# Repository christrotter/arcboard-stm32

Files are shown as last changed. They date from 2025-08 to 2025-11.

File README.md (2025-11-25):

# 2025/11/25 update
Ok, we found the main problem.
The Schottky diode on the main VBUS inbound power leg (just after the main polyfuse) was the problem.  After many hours of troubleshooting, we discovered that it was the thing getting hot.
More digging revealed that it had a 1A max, and after 75C its performance tanked pretty fast.  In practice it could tolerate about 0.5A before overheating got out of hand.
I replaced it with a bodge wire and the overheating problem went away - the board is now just warm with 1.1A going through it - probably some other components are 1A-rated.  I did not anticipate drawing this much current... my bad!
As a side effect of removing the diode, VBUS detection no longer works properly, so that needs to be disabled in code.

The next iteration will be a massive overhaul, so I'm not going to fix the problem.  In theory, we need both a higher quality component, a bigger package, and higher current rating.

# 2025/11/23 update 
I've, unsurprisingly, found some flaws.
Aside from the flaws mentioned (that were fixed), there's something very wrong with the power filter circuit or power trace widths.
Everything works, but it consumes 2x the power it should be consuming, and overwhelms the power traces so that they get rather hot.  I had to reduce brightness quite a bit to keep it at 'warm' levels.  Unfortunately I don't own an infrared camera, so only have temperature sensing by feel, but the area that gets hottest is in the power filter area.  I tried using the solder pad bypass, but no difference.
So, feels like it's a trace problem...?  Or maybe a bad component?  Will update when I figure it out.
If you're only running the Cyboard pcbs, PMW, dpad/paddles, it consumes about 0.25A per side.

# stm32-inator
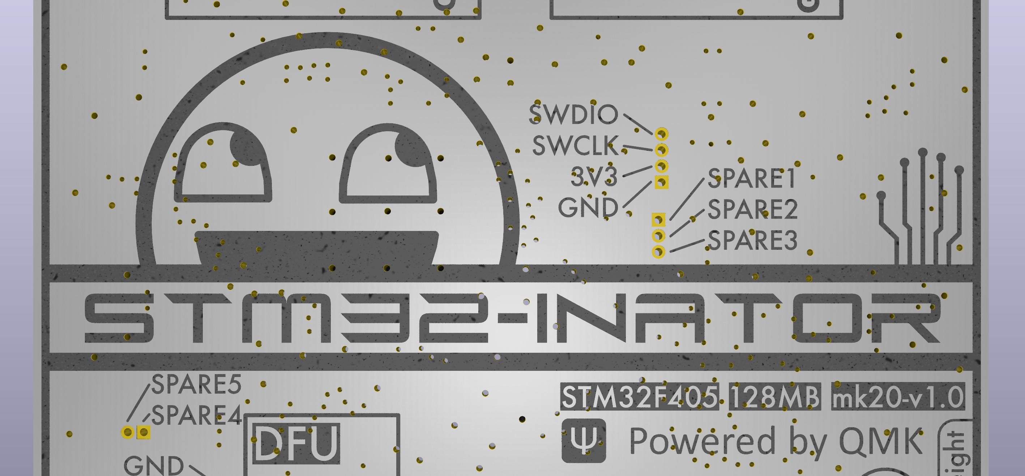
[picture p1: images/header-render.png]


In the search for better performance, I moved from [RP2040](https://github.com/christrotter/mk19-rp2040) (`125mhz`) to STM32F405 (`168mhz`).  Getting familiar with STM32 also allows me more confidence to move to the H7** chips in future (`550mhz`).

`v1.0 board has been tested - works w. 2 easy bodges & code.  Issues fixed in v1.1 - won't be ordering that, so untested - minor changes, should be fine?`

Many thanks to Drashna, burkfers, GeorgeN, badjeff, and the various people (tzarc) I snaggled stuff from - as always, these projects are a community effort.

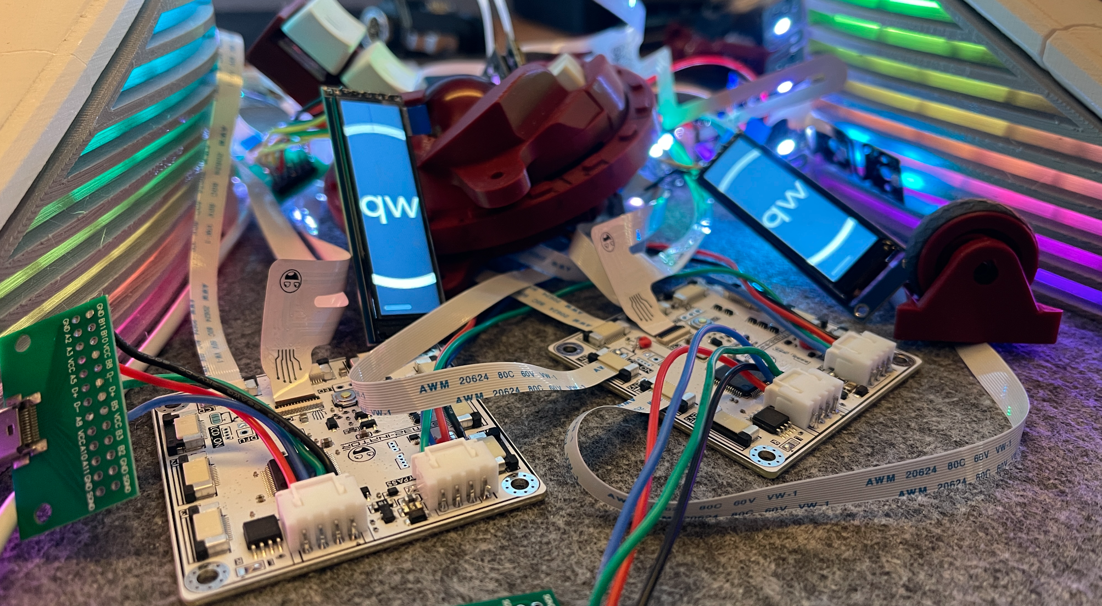
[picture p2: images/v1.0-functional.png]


## First run production
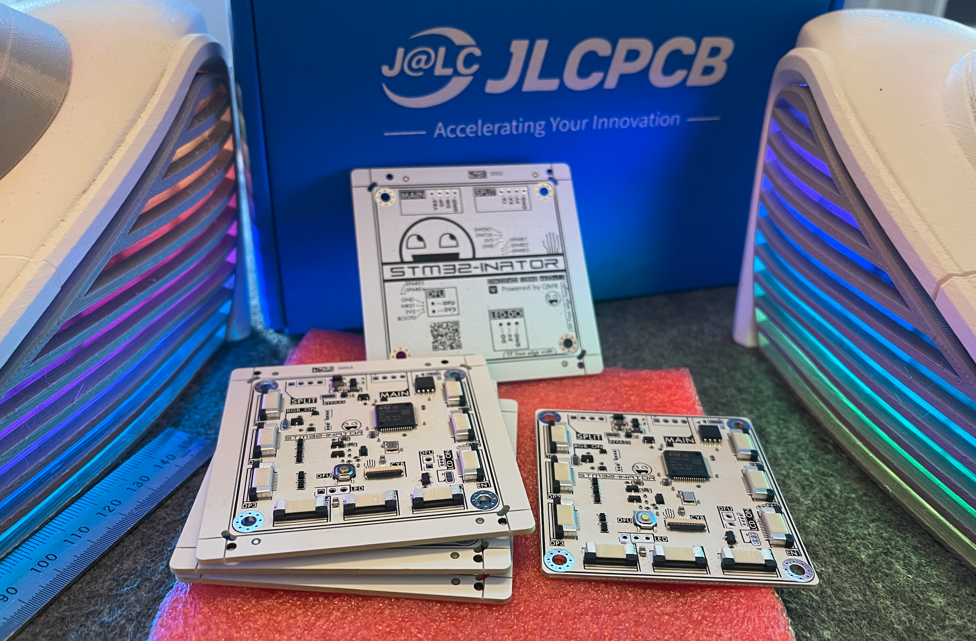
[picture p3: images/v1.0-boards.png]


### issues
While things work, there are some problems...
- both mosfets are incorrectly wired up (maybe bad footprint?), and frankly i don't see a need for them as we're not doing batteries; the original thought was 'full power down', dunno if that's a real need; clipping them off removes the issue, and there are sufficient workarounds
- the DFU circuit cannot tolerate the LCD being plugged in; something? in that circuit prevents the cap from charging up
  - there is something foundational here that I am not equipped to deal with atm; 'works, until 3v3 devices in play'

### discoveries
...and some 'you have to try it to know' discoveries, and secondary pcb issues...
- 8mhz crystal is not the default in QMK -> 12mhz is; can be fixed in a few lines of code, but not ideal
- turns out 10 ffc cables are pretty annoying and i'd have been better served moving to two custom ffc cables
- the ffc connectors are kinda sad to use; need to make some kind of tool? -> kinda points in the direction of hot plate if i want to be choosy about parts
- the horizontal JST-XH fit...barely... i neglected to account for 'space to slide the connector in' and so you need to trim the JST housings to avoid fouling on parts - move away from this design in future, JST-PH?

### wins
...but not all is lost:
- remote usb port works absolutely fine
- DFU circuit is super rad (when it works)
- no awful bodging required this time!
- the diode arrays work
- STM32 cpu/etc all works
- silkscreen looks good
- matrix works
- spi pmw/lcd work

### conclusion
All in all, this is a win, and it'll work for mk20.

# Features
- STM32F405RGTx w. 12mhz crystal
- 128mb external flash via SPI
  - Because I Can™ by drashna®
- FFC connections (mostly), using VIK-footprinted 12-pin 0.5mm pitch connectors
- Rough footprint is 60x60mm
- Designed for remote-mount USB and split-serial ports
- WS2812 signal conversion to 5v
- Two-stage DFU button, on-board for convenience, headers for an external button
  - Press for reset
  - Hold for ~4s to enter DFU mode for flashing
  - `NOTE: when 3v3 devices are connected, the hold-for-dfu stops working :'(`
- Designed for Arcboard-mk20 peripherals
  - 4x dpad outputs (5rows, 1col, LED DI/DO, 5v/gnd)
  - 3x encoders outputs (encoder A/B, 3.3v/gnd)
  - 1x SPI PMW output (usual pins)
  - 1x SPI LCD output (usual pins)
  - 1x 25-pin Cyboard connector (0.3mm FPC connector for [Cyboard](https://www.cyboard.digital/product-page/dactyl-flex-pcbs) connectivity (or via [this](https://github.com/christrotter/mk19-flex-pcb)))
- 2-layer design for simplicity and cost

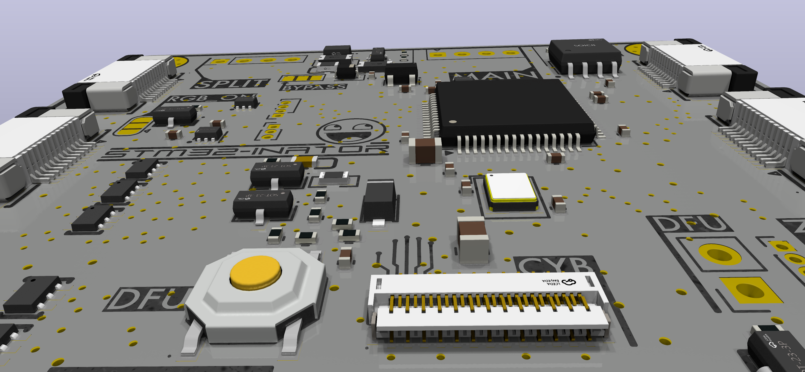
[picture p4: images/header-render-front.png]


# Design notes & decisions
## CPU
I had originally wanted to go whole-hog and start with STM32H723 (as mentioned, 550mhz), but there are a lot of Chibios/QMK config bits to set that are not well-documented at present.  As 550mhz is super overkill for a keyboard, it's not a widely used chip - so examples are sparse or non-existent.

Drashna recommended starting with F405 and so who am I to second-guess them.

## Flash
At present (August 2025) QMK cannot support external flash for code execution, but feature work is on-going.  I was advised by Drashna to include the flash chip for future-proofing.  My hope is to use it for icon storage and the like.

Why 128mb?  Because it was a few bucks difference compared to 16mb, and there was no real (evident) reason not to.

## Remote-mount USB/split-serial port
This is mostly a mk20 design thing - I wanted to have the split-serial connector be at an angle, not coming off the back of the board.  When the ports are in the back, it's awkward to figure out which one is main, which one is split.  Drashna pointed out that he's been using [these](https://www.aliexpress.com/item/1005005997783735.html) which have 12cm cables and has no USB issues at all.  After a hiccup with JLC PCBA design review, I had to cancel the order and re-submit, and took the plunge...there was no room for both an on-board port and breakout pins.

  - JLC PCBA charges ~C$6 per usb port (per board...), and I've had soldering issues w. those components before
  - No more fuss with v-cut layer drama and them wanting me to use EasyEDA
  - I don't have a USB-C source, and I'm not selling this, so...whatever...
  - note that the remote-port needs to have 5.1k pull-down resistors on the CC lines to function on a USB-C host port

## Device/peripheral connectivity
I explicitly wanted to move away from JST-XH (or any soldered connector) because of pain issues doing all that soldering.  This board's goal was 'minimize soldering, maximize PCBA-ing'.

Given that I like the [VIK standard](https://github.com/sadekbaroudi/vik), I went with VIK footprints - 12-pin 0.5mm pitch FFC.  Not all of the pinouts are VIK-correct, but at least it keeps things somewhat standardized.

## Breakouts
To save space while also future-proofing, I was advised to include breakouts (thx GeorgeN/burkfers).

- Main USB & Split/serial via 2.54mm 4-pin header (I left room for a horizontal JST-XH socket)
- RGB data output via 2.54mm 3-pin header
- Reset, boot pins via 1.00mm 4-pin header
- 5 spare pins via 1.00mm 2-pin and 3-pin headers
- Debug pins via 1.00mm 4-pin header

## Spare pins
The 5 spare pins were initially going to be used for the matrix, but I cut out some features (RKJXT) and didn't need them.  They are available via headers.

Suggestions I've had:
- audio
- haptic

## Solder pads
There are a number of 'config' settings you can achieve using solder pads.  I had originally thought about using DIP switches or something...but burkfers counseled me to just stick with solder pads.

- Set [handedness](https://docs.qmk.fm/features/split_keyboard#handedness-by-pin)
- Bypass VBUS power safeties (I keep this in because I don't know what a fuse failure would look like)
- "turn on" power to the RGB and LCD mosfets

## PCB design
I decided to stick with a 2-layer stackup because I was already comfortable with using pours and vias to keep the ground plane consistent.  We'll see if that pans out.

It's important to note that if you don't provide for good ground pathing 2-layers is a bad choice.  It's "easier" to do a 4-layer board in that regard.

When ordering, I used the 'rails by JLC' option.

## Dimensions
[The RP2040 board](https://github.com/christrotter/mk19-rp2040) was `~125x75mm`, and burkfers challenged me to make this one more compact.  So a few design iterations in and we got `~60x60mm`... which unfortunately got mangled to `59.5x59.7mm`.  I'm still learning pcb design, and Kicad doesn't make it easy (or I have yet to learn the method) to keep things oriented/placed relative to center.

- 51.55mm hole spacing (square)
- M3 holes
- 59.5x59.7mm actual board size

## Matrix arrangement
I moved away from the SPI register design not because it was broken, but because you are effectively artificially limiting 'speed' with the SPI bus (sort of?).  I'm using `ROW2COL` because the Cyboard pcb's are designed this way.  

I decided to try diode "arrays" ([BAV70S - High-speed switching double diode](https://jlcpcb.com/partdetail/Nexperia-BAV70S115/C455031)) this time to save space.  However, this came with some fairly dramatic trace routing challenges.

- 6 rows
- 10 columns

## QMK
I mention `ROW2COL` and QMK not because ZMK or other won't work, but because it's what I am familiar with.

This board is intended to control half of a split keyboard, so you need two.

# Links
- [Datasheet for STM32F405](https://www.st.com/resource/en/datasheet/dm00037051.pdf)
- [Great article on STM32 DFU circuit](https://acheronproject.com/reset_article_1/reset_article_1/)
- [Great article on USB-C CC lines](https://hackaday.com/2023/01/04/all-about-usb-c-resistors-and-emarkers/)
- [TI pdf on USB-C power](https://www.ti.com/lit/wp/slyy109b/slyy109b.pdf)
- [USB and Type-C demystified](https://www.st.com/content/dam/AME/2019/technology-tour-2019/chicago/presentations/T1S3_Schaumburg_USB-Type-C_G.Gosciniak.pdf)
- [SPI flash on STM32](https://mischianti.org/stm32-add-spi-flash-memory-with-fat-fs/)

# BOM (v1.1)
|Designator |Footprint |Quantity|Value |LCSC Part #|
|---|---|---|---|---|
|C1, C10, C20 |0805 |3 |4.7uF |C1779 |
|C11, C12, C14, C17, C18, C19, C5, C7, C8, C9|0402 |10 |100nF |C1525 |
|C13, C15, C27 |0402 |3 |1uF |C52923 |
|C2, C4 |0402 |2 |2.2uF |C12530 |
|C22 |C0603 |1 |CL10A106MA8NRNC |C96446 |
|C3, C6 |0402 |2 |12p |C1547 |
|CYBOARD-MAIN1 |FPC-SMD_ECT818001569 |1 |ECT818001569 |C711420 |
|D2 |D_SOD-323 |1 |B5817 |C123899 |
|D4 |SOD-123FL_L2.8-W1.8-LS3.7-BI |1 |SMF5_0CA_C364279 |C364279 |
|D5, D7 |SOT-666-6_L1.6-W1.2-P0.50-LS1.6-BL |2 |USBLC6-2P6_C2827693 |C2827693 |
|F1 |F1206 |1 |Polyfuse |C2892424 |
|F3 |F1206 |1 |MF-NSMF075-2 |C89653 |
|J13, J14, J15, J16, J3, J4, J6, J7, J8 |FFC-SMD_FFC05001-12SBA124W5M |9 |FFC05001-12SBA124W5M|C2833760 |
|L1 |L0805 |1 |MPZ2012S101AT000 |C15957 |
|LED-LVL1 |SOT-563_L1.6-W1.2-P0.50-LS1.6-BR |1 |SN74LVC1T45DRL |C352970 |
|MOSFET1, MOSFET2, MOSFET3 |SOT-23_L2.9-W1.3-P1.90-LS2.4-BR |3 |AO3401A |C15127 |
|R1 |0402 |1 |0402WGF1004TCE |C26083 |
|R10 |0402 |1 |5.1k |C25905 |
|R11, R12, R16, R2, R3, R7, R8 |0402 |7 |10k |C25744 |
|R14 |0402 |1 |0402WGF1000TCE |C25076 |
|R15 |0402 |1 |0402WGF1001TCE |C11702 |
|R6 |R0603 |1 |0603WAF3303T5E |C23137 |
|R9 |0402 |1 |0402WGF1003TCE |C25741 |
|U1 |SOT-23-5 |1 |XC6210B332MR-G |C82942 |
|U10 |SOD-123F_L2.7-W1.6-LS3.8-RD |1 |1N4148W_C81598 |C81598 |
|U13, U4 |SOT-23-3_L2.9-W1.3-P1.90-LS2.4-BR |2 |2N7002 |C8545 |
|U14 |SOIC-8_L5.3-W5.3-P1.27-LS8.0-BL |1 |W25Q128JVSIQTR |C97521 |
|U15 |SW-SMD_4P-L5.1-W5.1-P3.70-LS6.5-TL_H1.5|1 |TS-1187A-B-A-B |C318884 |
|U3 |LQFP-64_10x10mm_P0.5mm |1 |STM32F405RGTx |C15742 |
|U5, U6, U7, U8, U9 |SOT-363-6_L2.0-W1.3-P0.65-LS2.1-BL |5 |BAV70S,115 |C455031 |
|Y1 |CRYSTAL-SMD_4P-L3.2-W2.5-BL-1 |1 |Crystal_GND24 |C9002 |

# Layout
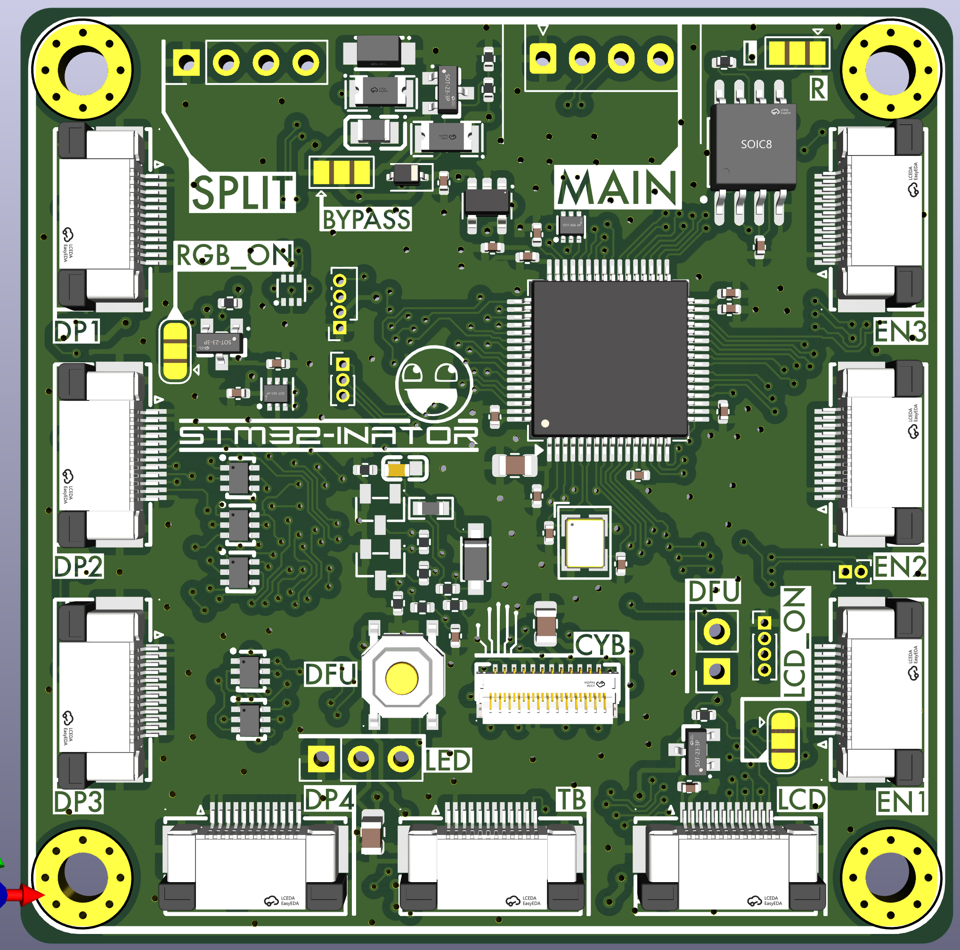
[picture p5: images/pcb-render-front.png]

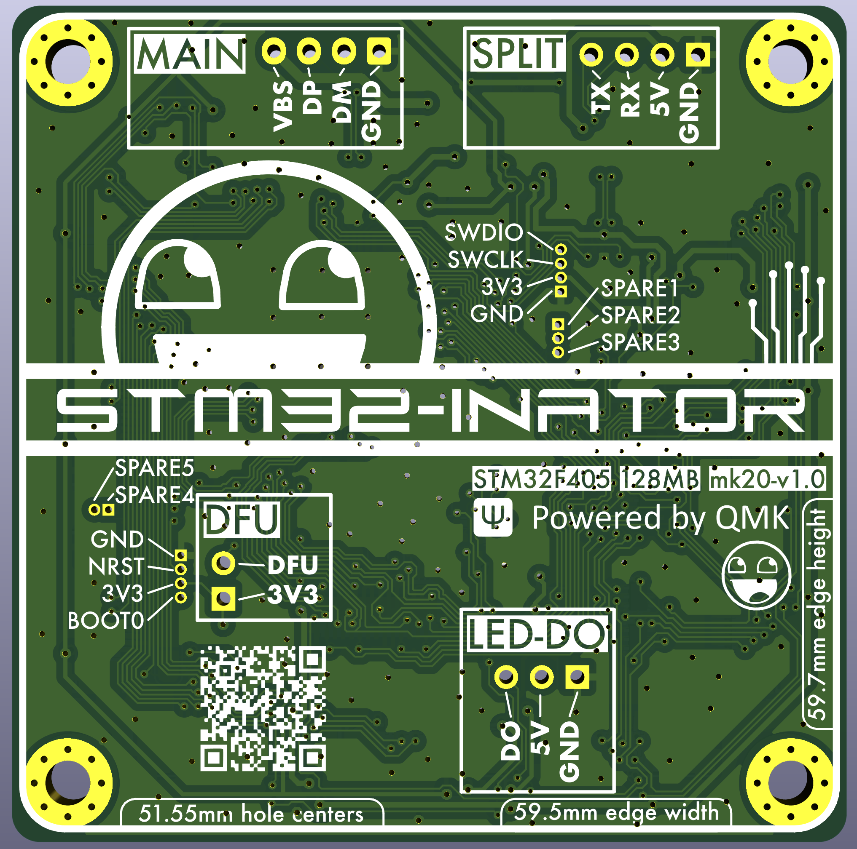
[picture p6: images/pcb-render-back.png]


# PCB overview
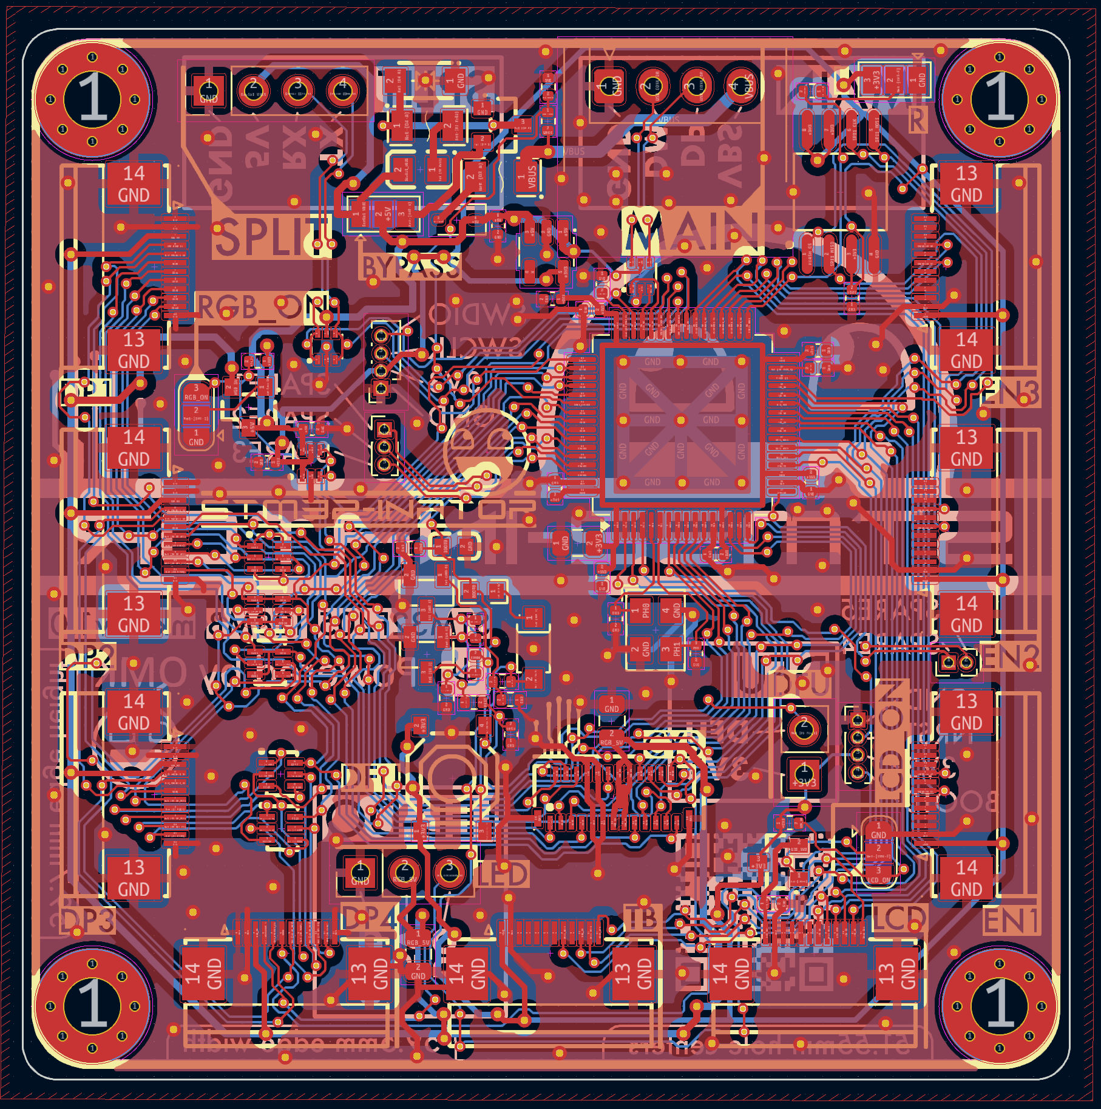
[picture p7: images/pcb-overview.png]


# Schematic
`NOTE: I didn't update the screenshots, sorry.  See the kicad files for the fixed mosfets.`
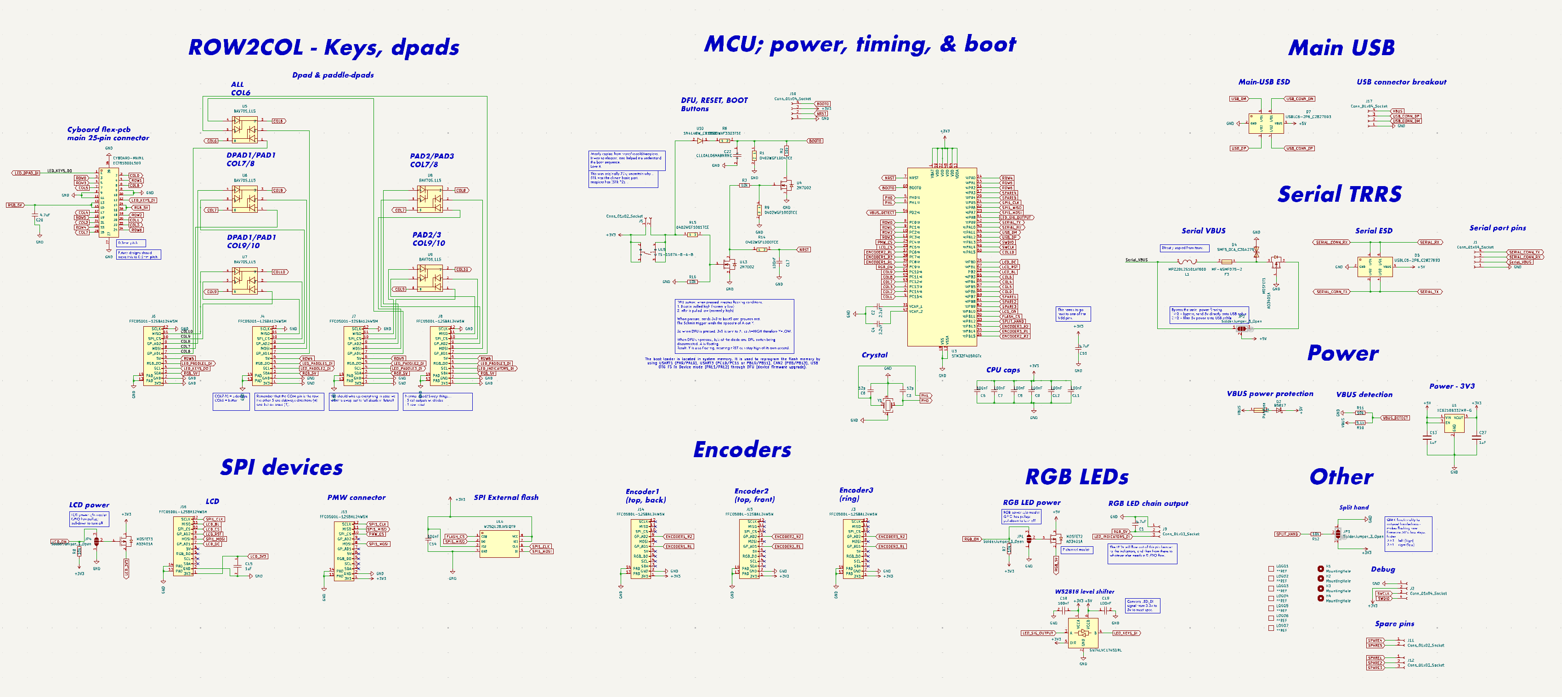
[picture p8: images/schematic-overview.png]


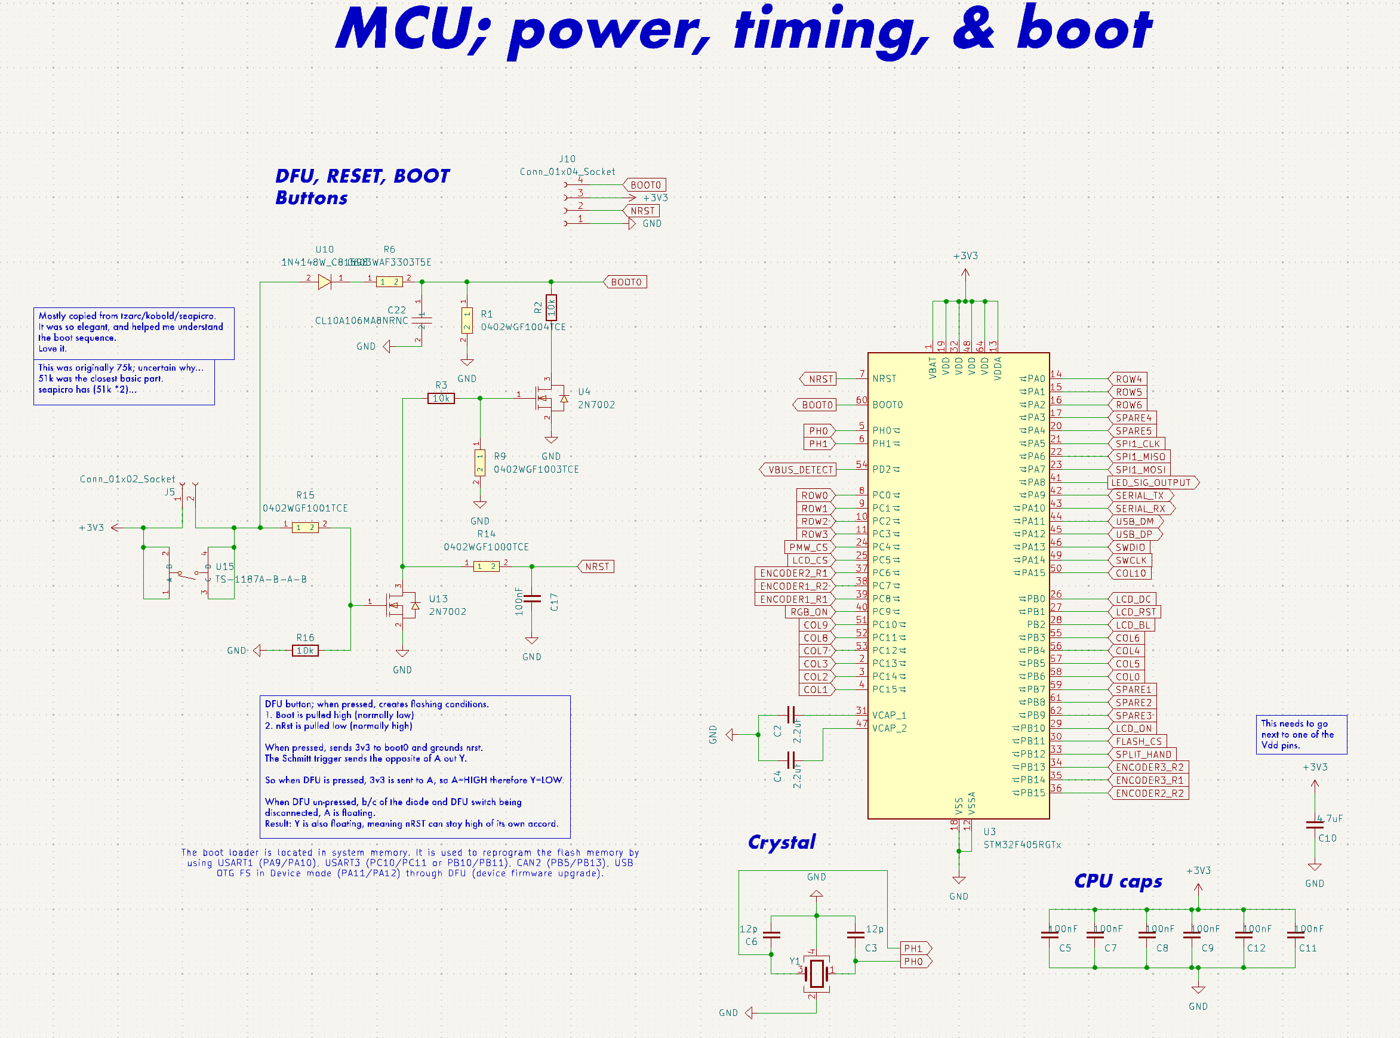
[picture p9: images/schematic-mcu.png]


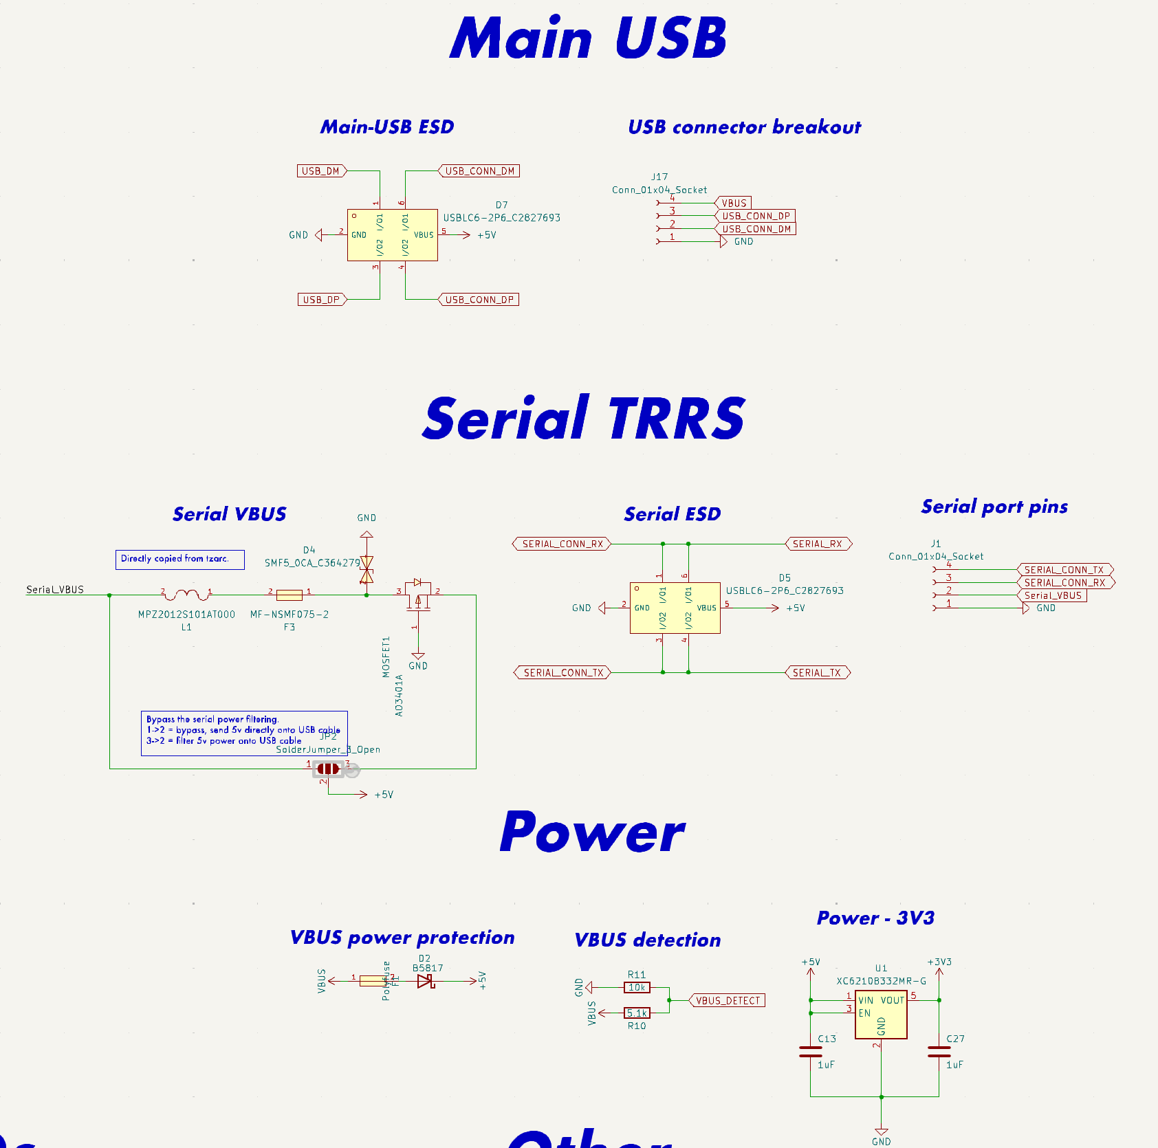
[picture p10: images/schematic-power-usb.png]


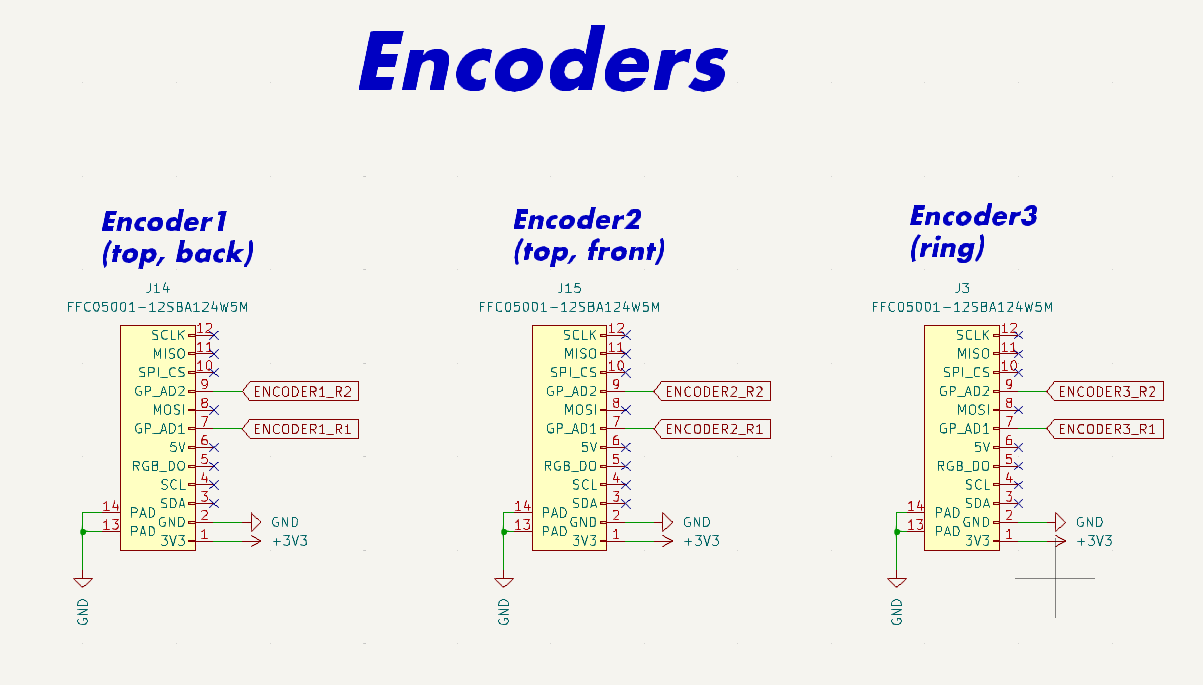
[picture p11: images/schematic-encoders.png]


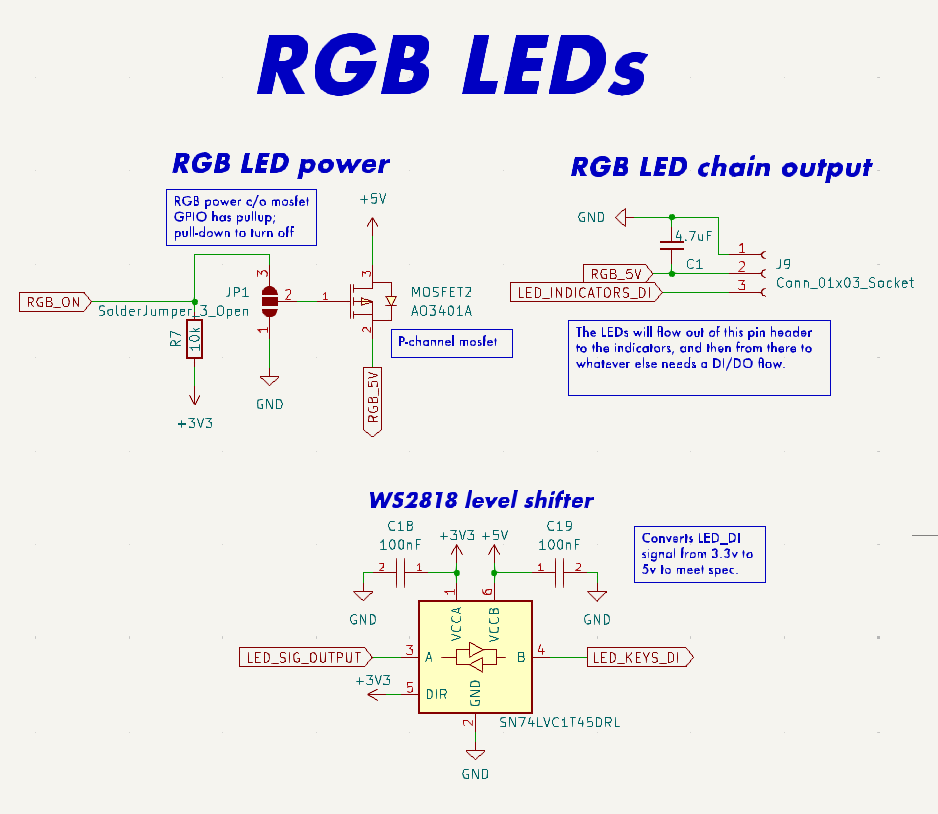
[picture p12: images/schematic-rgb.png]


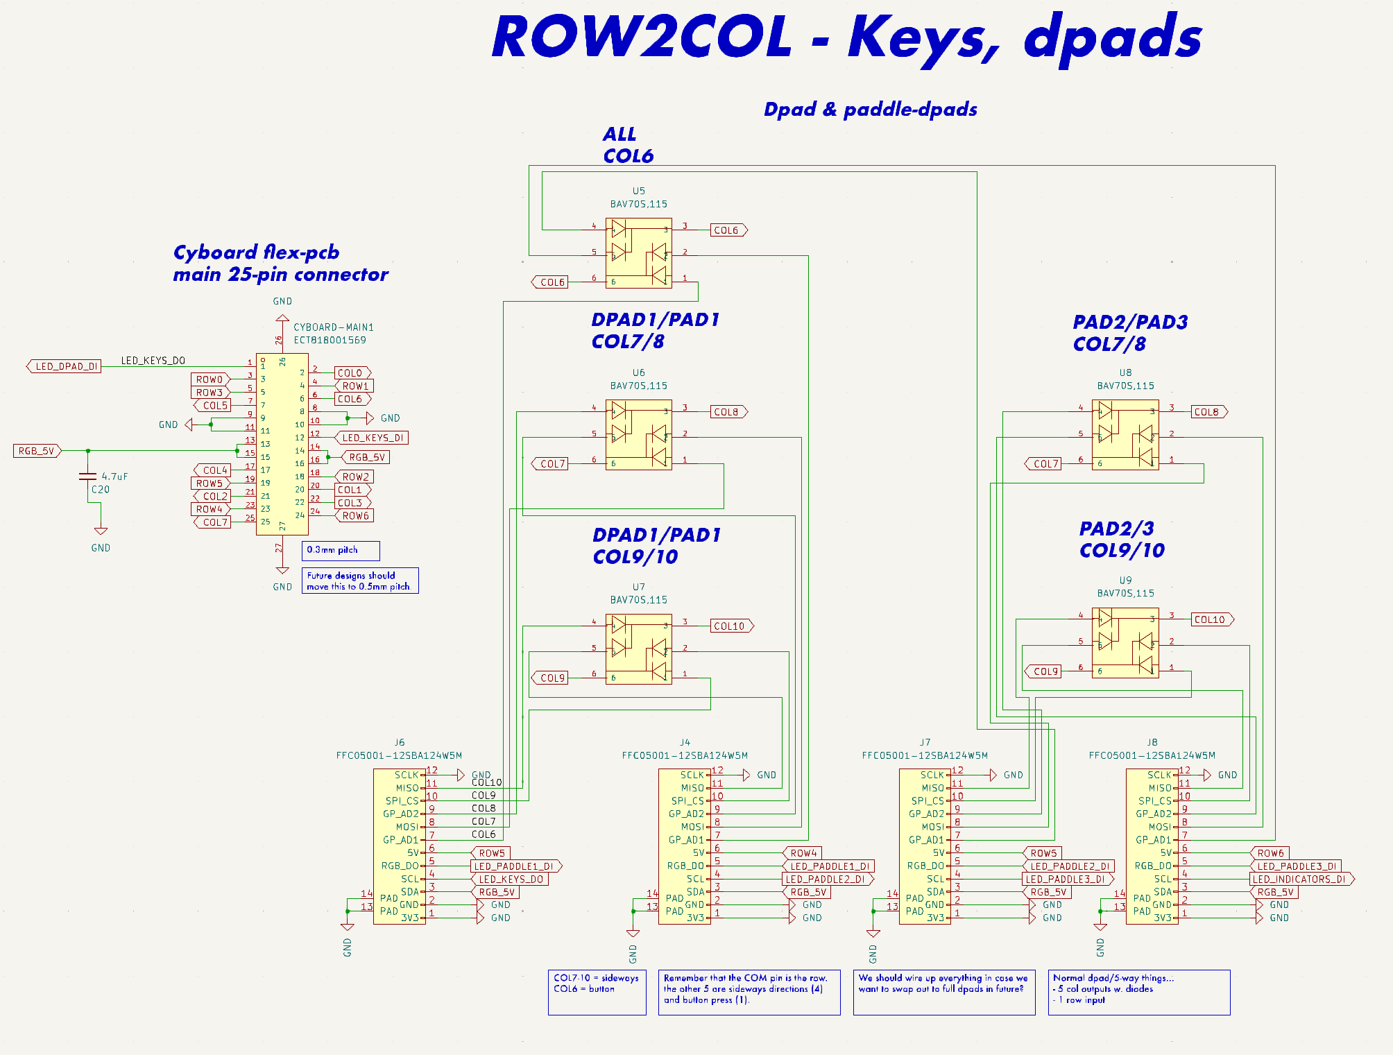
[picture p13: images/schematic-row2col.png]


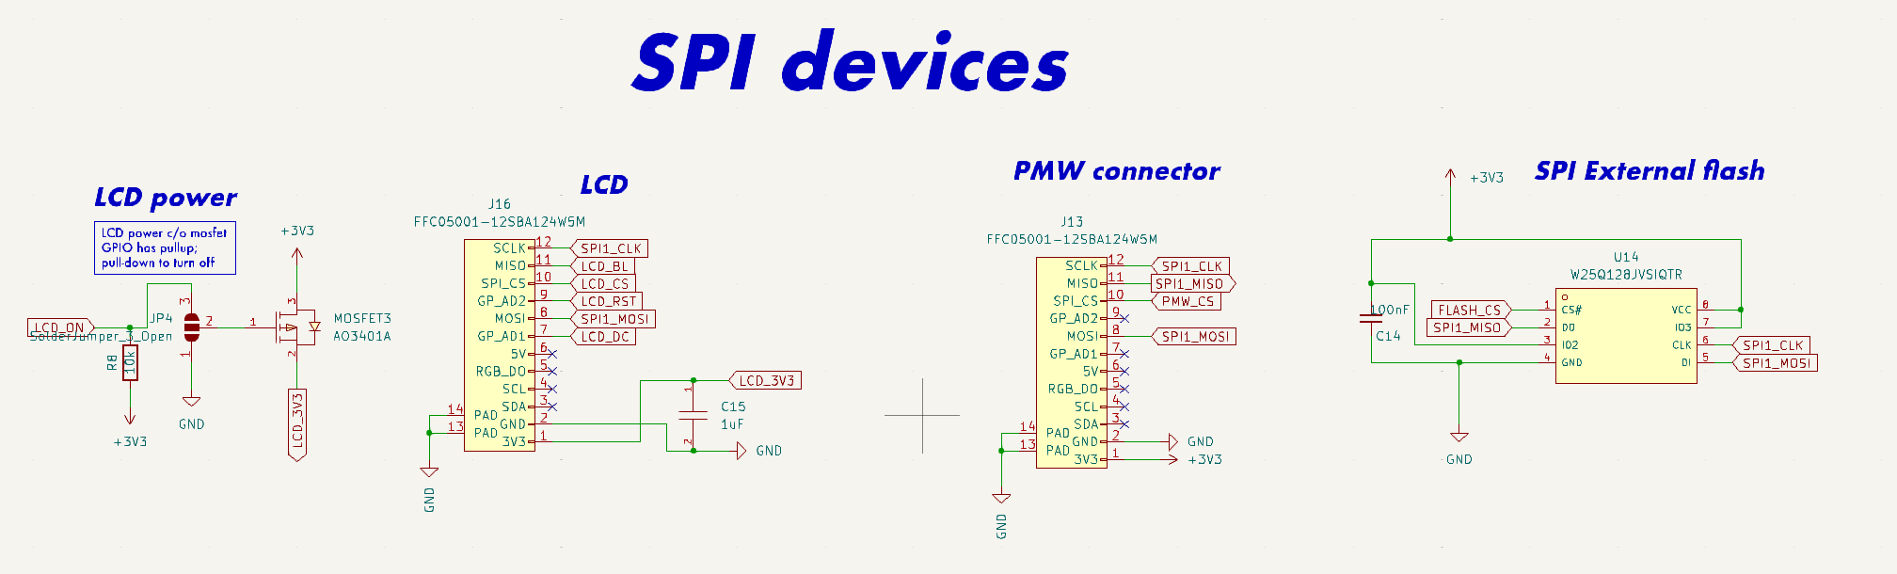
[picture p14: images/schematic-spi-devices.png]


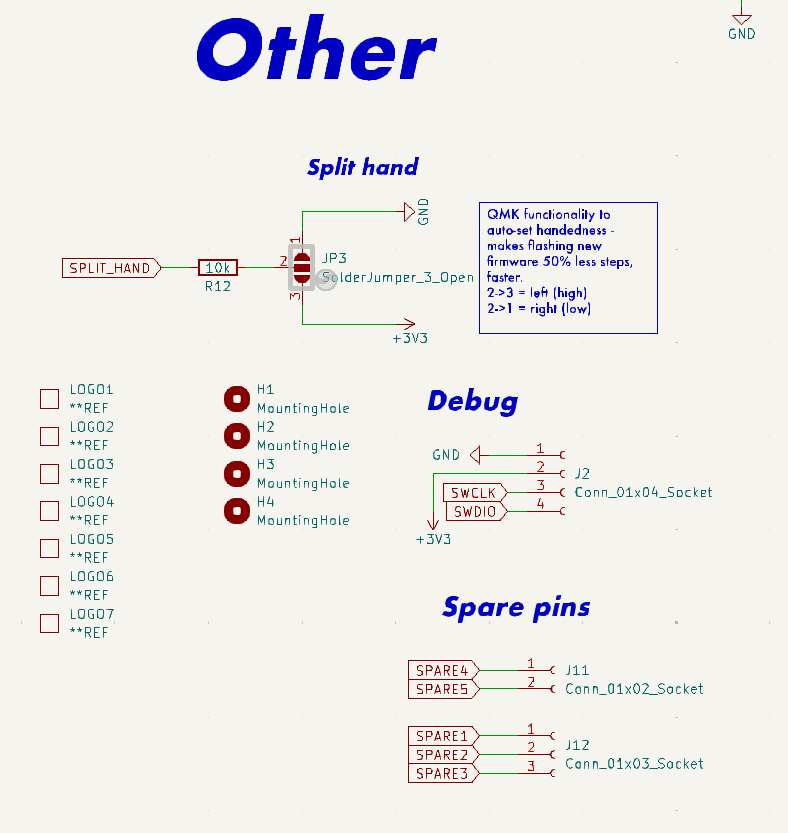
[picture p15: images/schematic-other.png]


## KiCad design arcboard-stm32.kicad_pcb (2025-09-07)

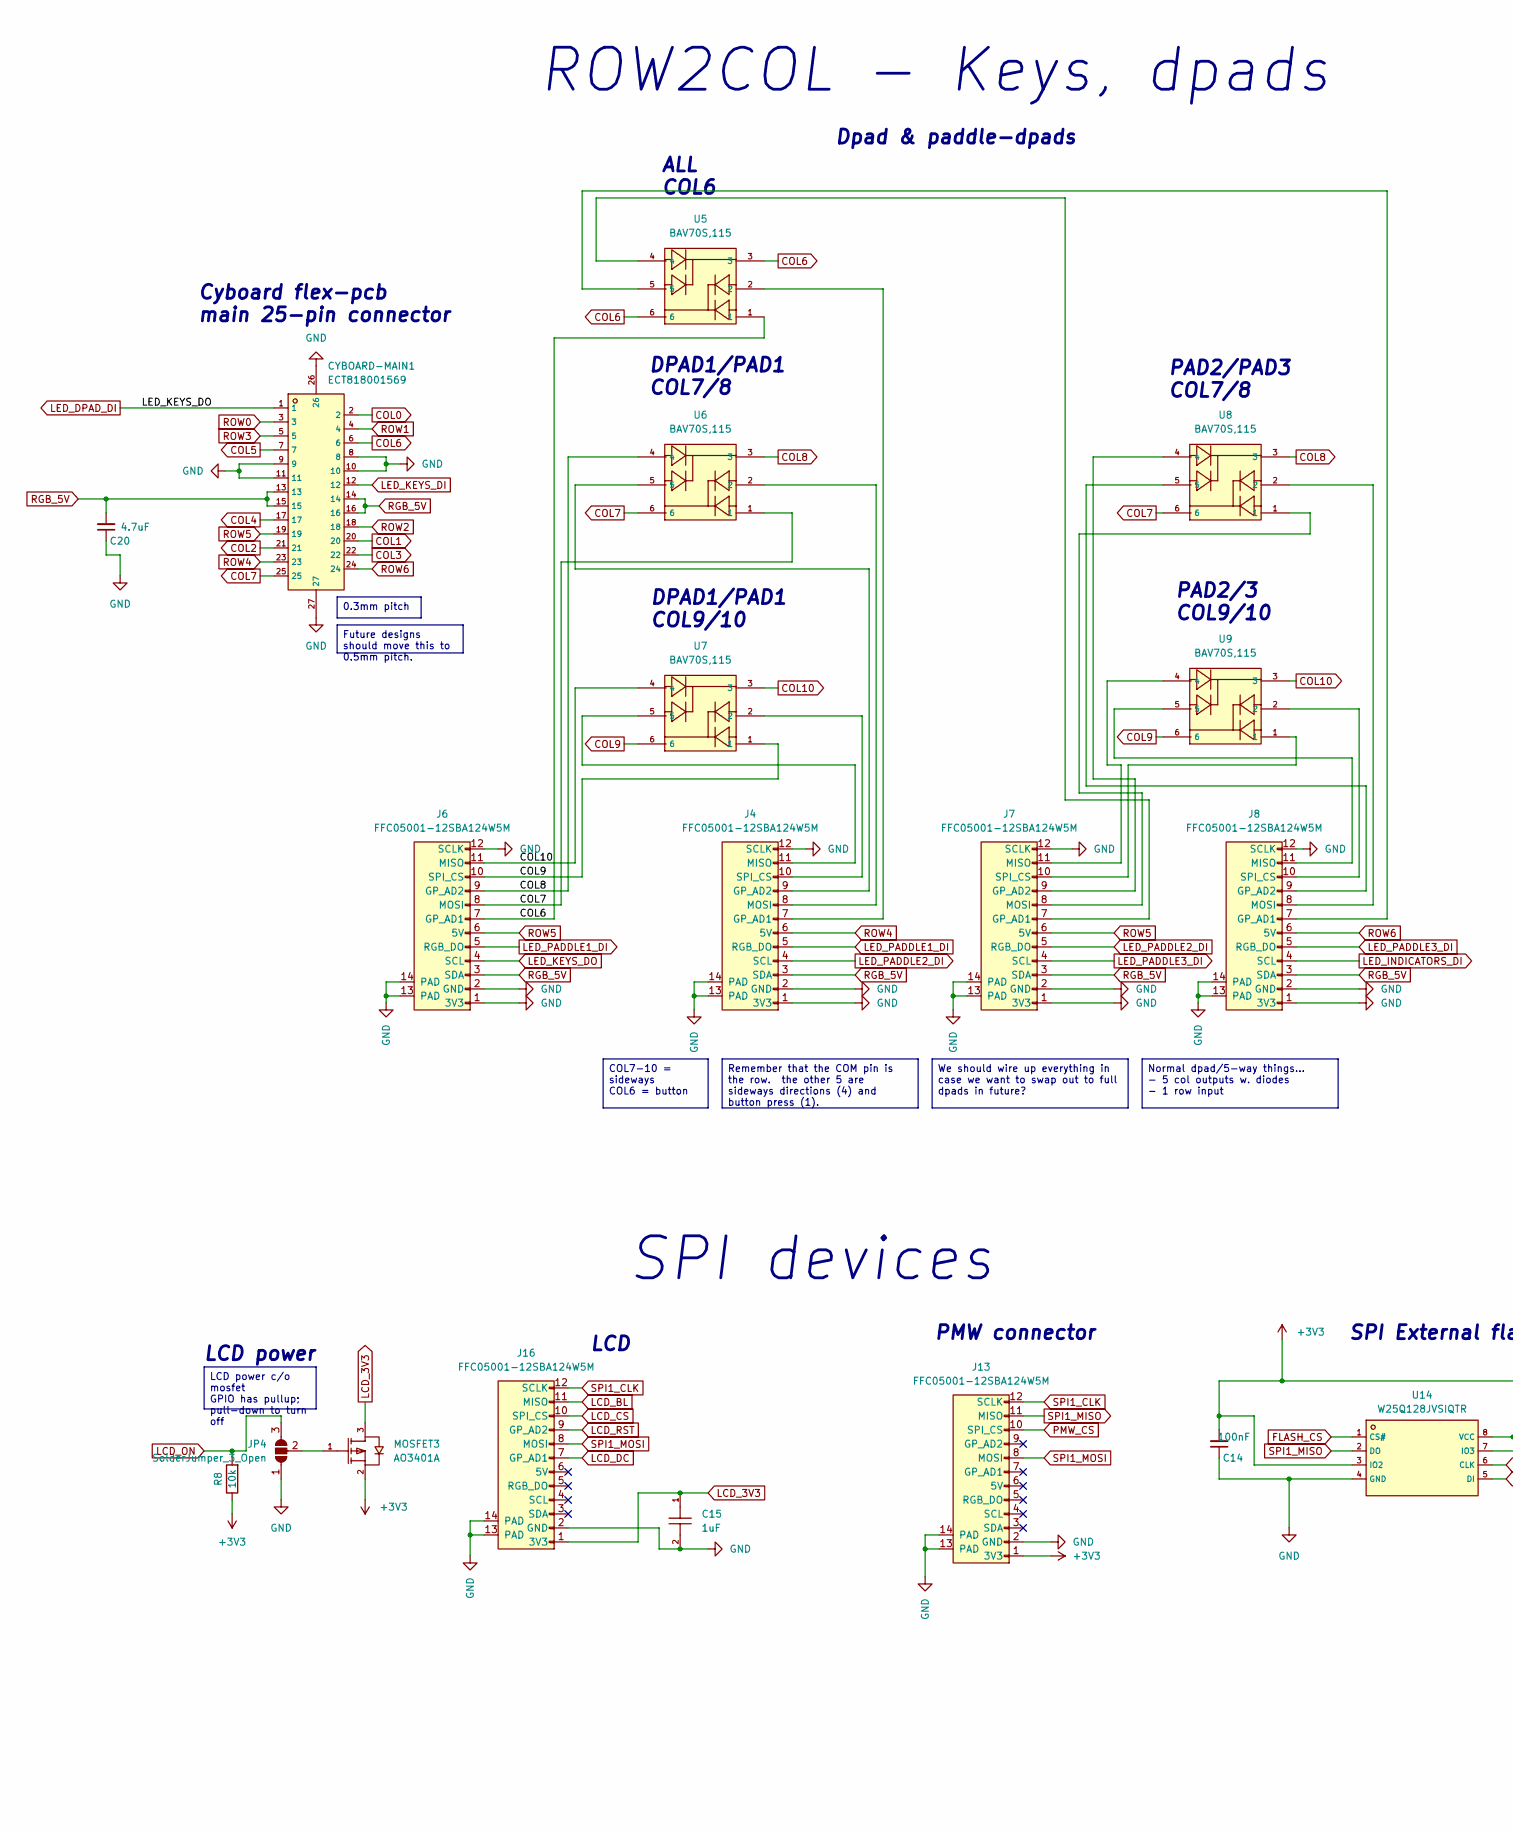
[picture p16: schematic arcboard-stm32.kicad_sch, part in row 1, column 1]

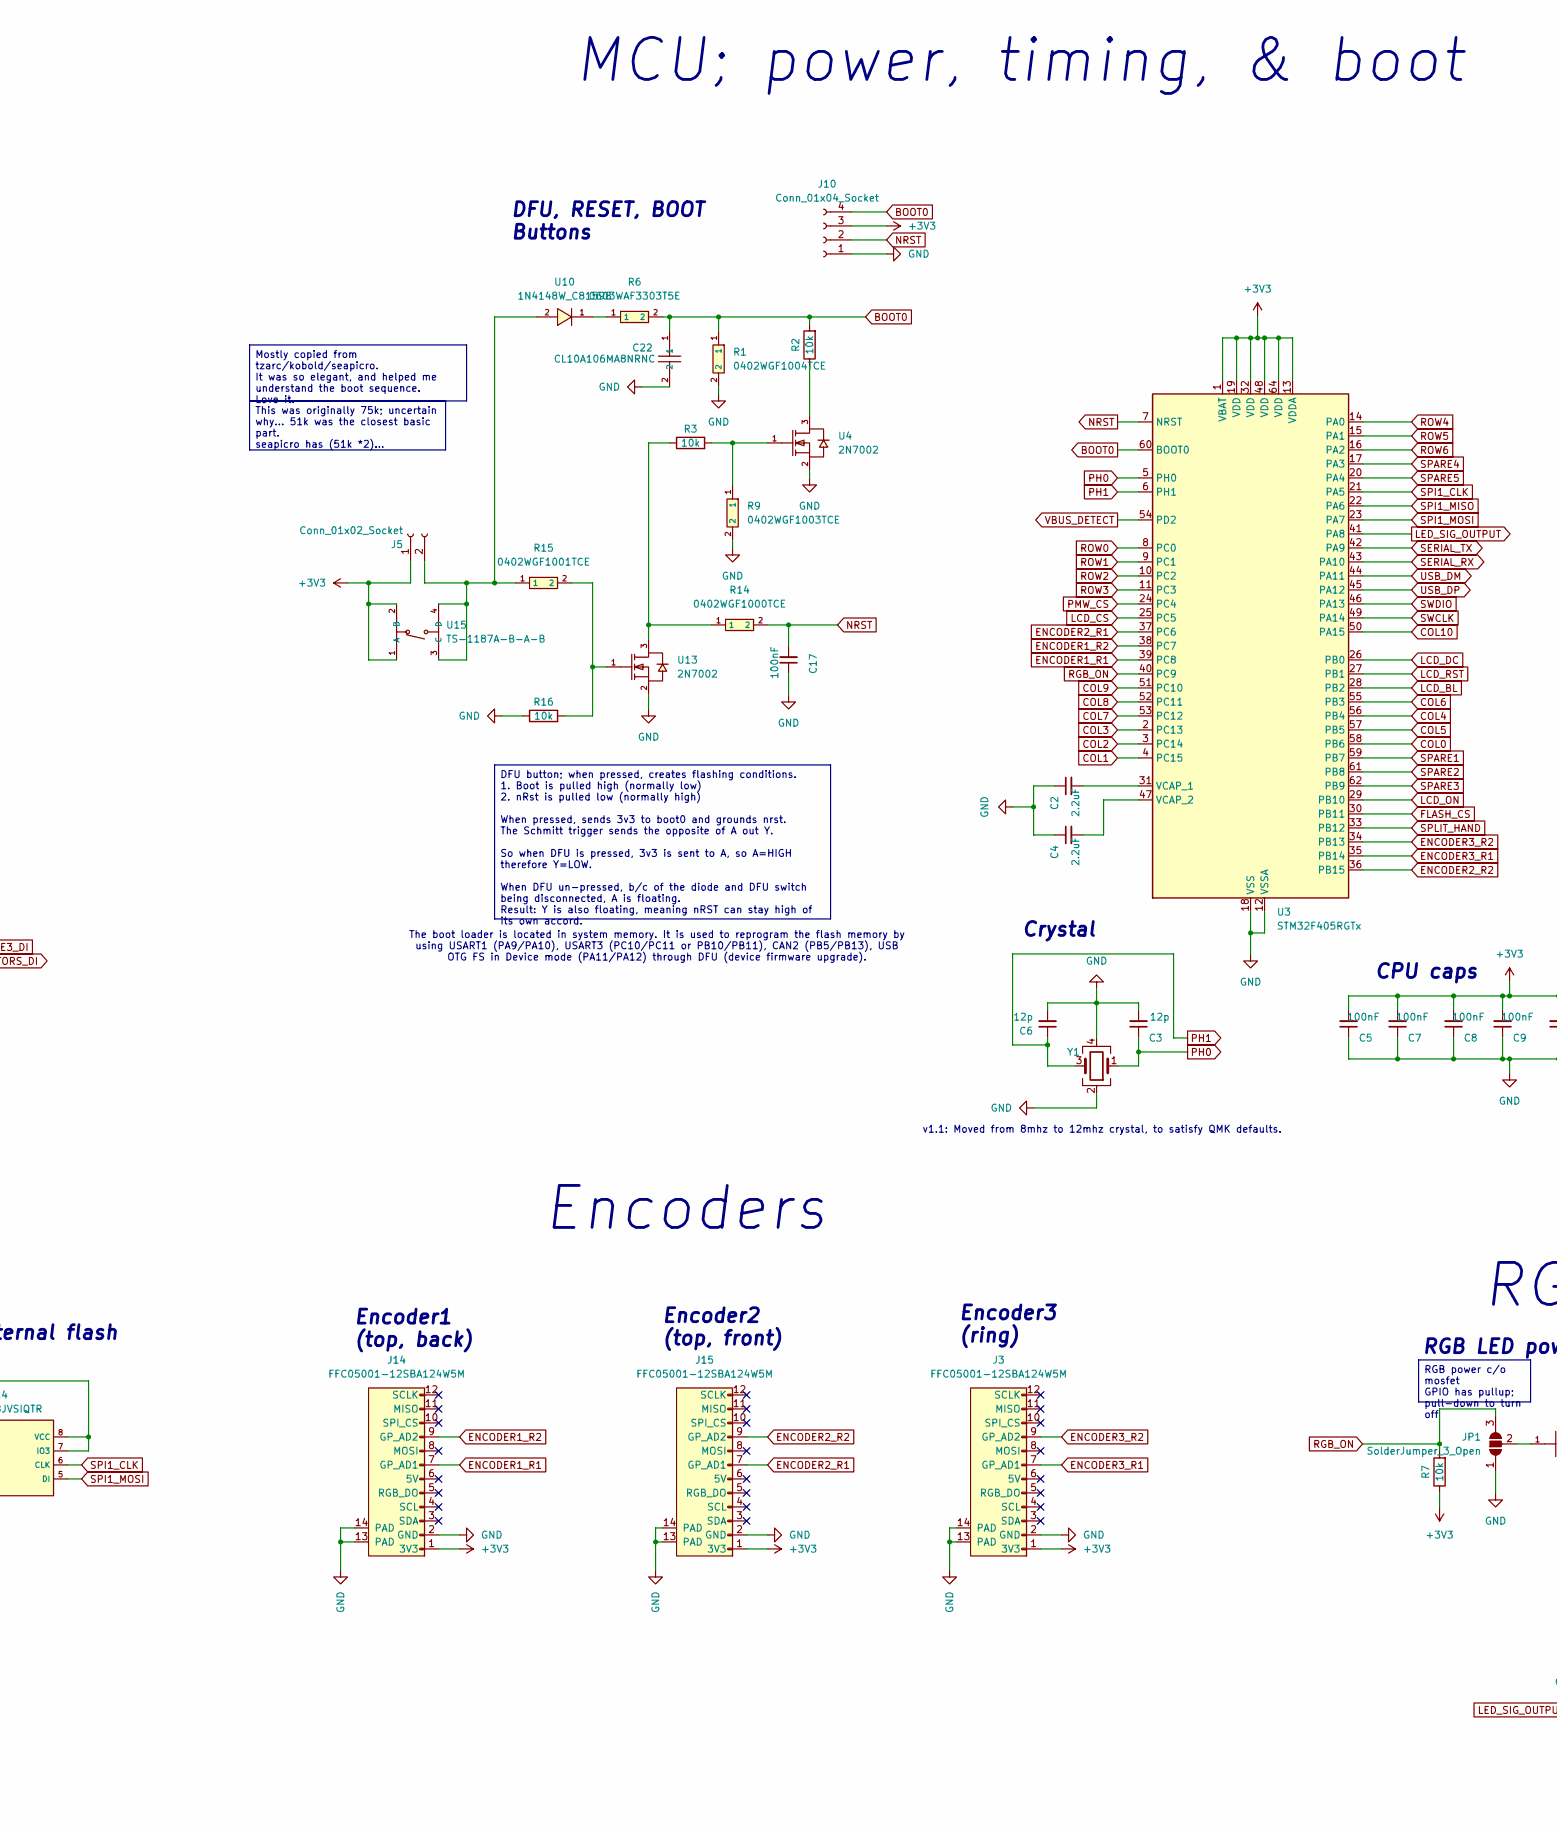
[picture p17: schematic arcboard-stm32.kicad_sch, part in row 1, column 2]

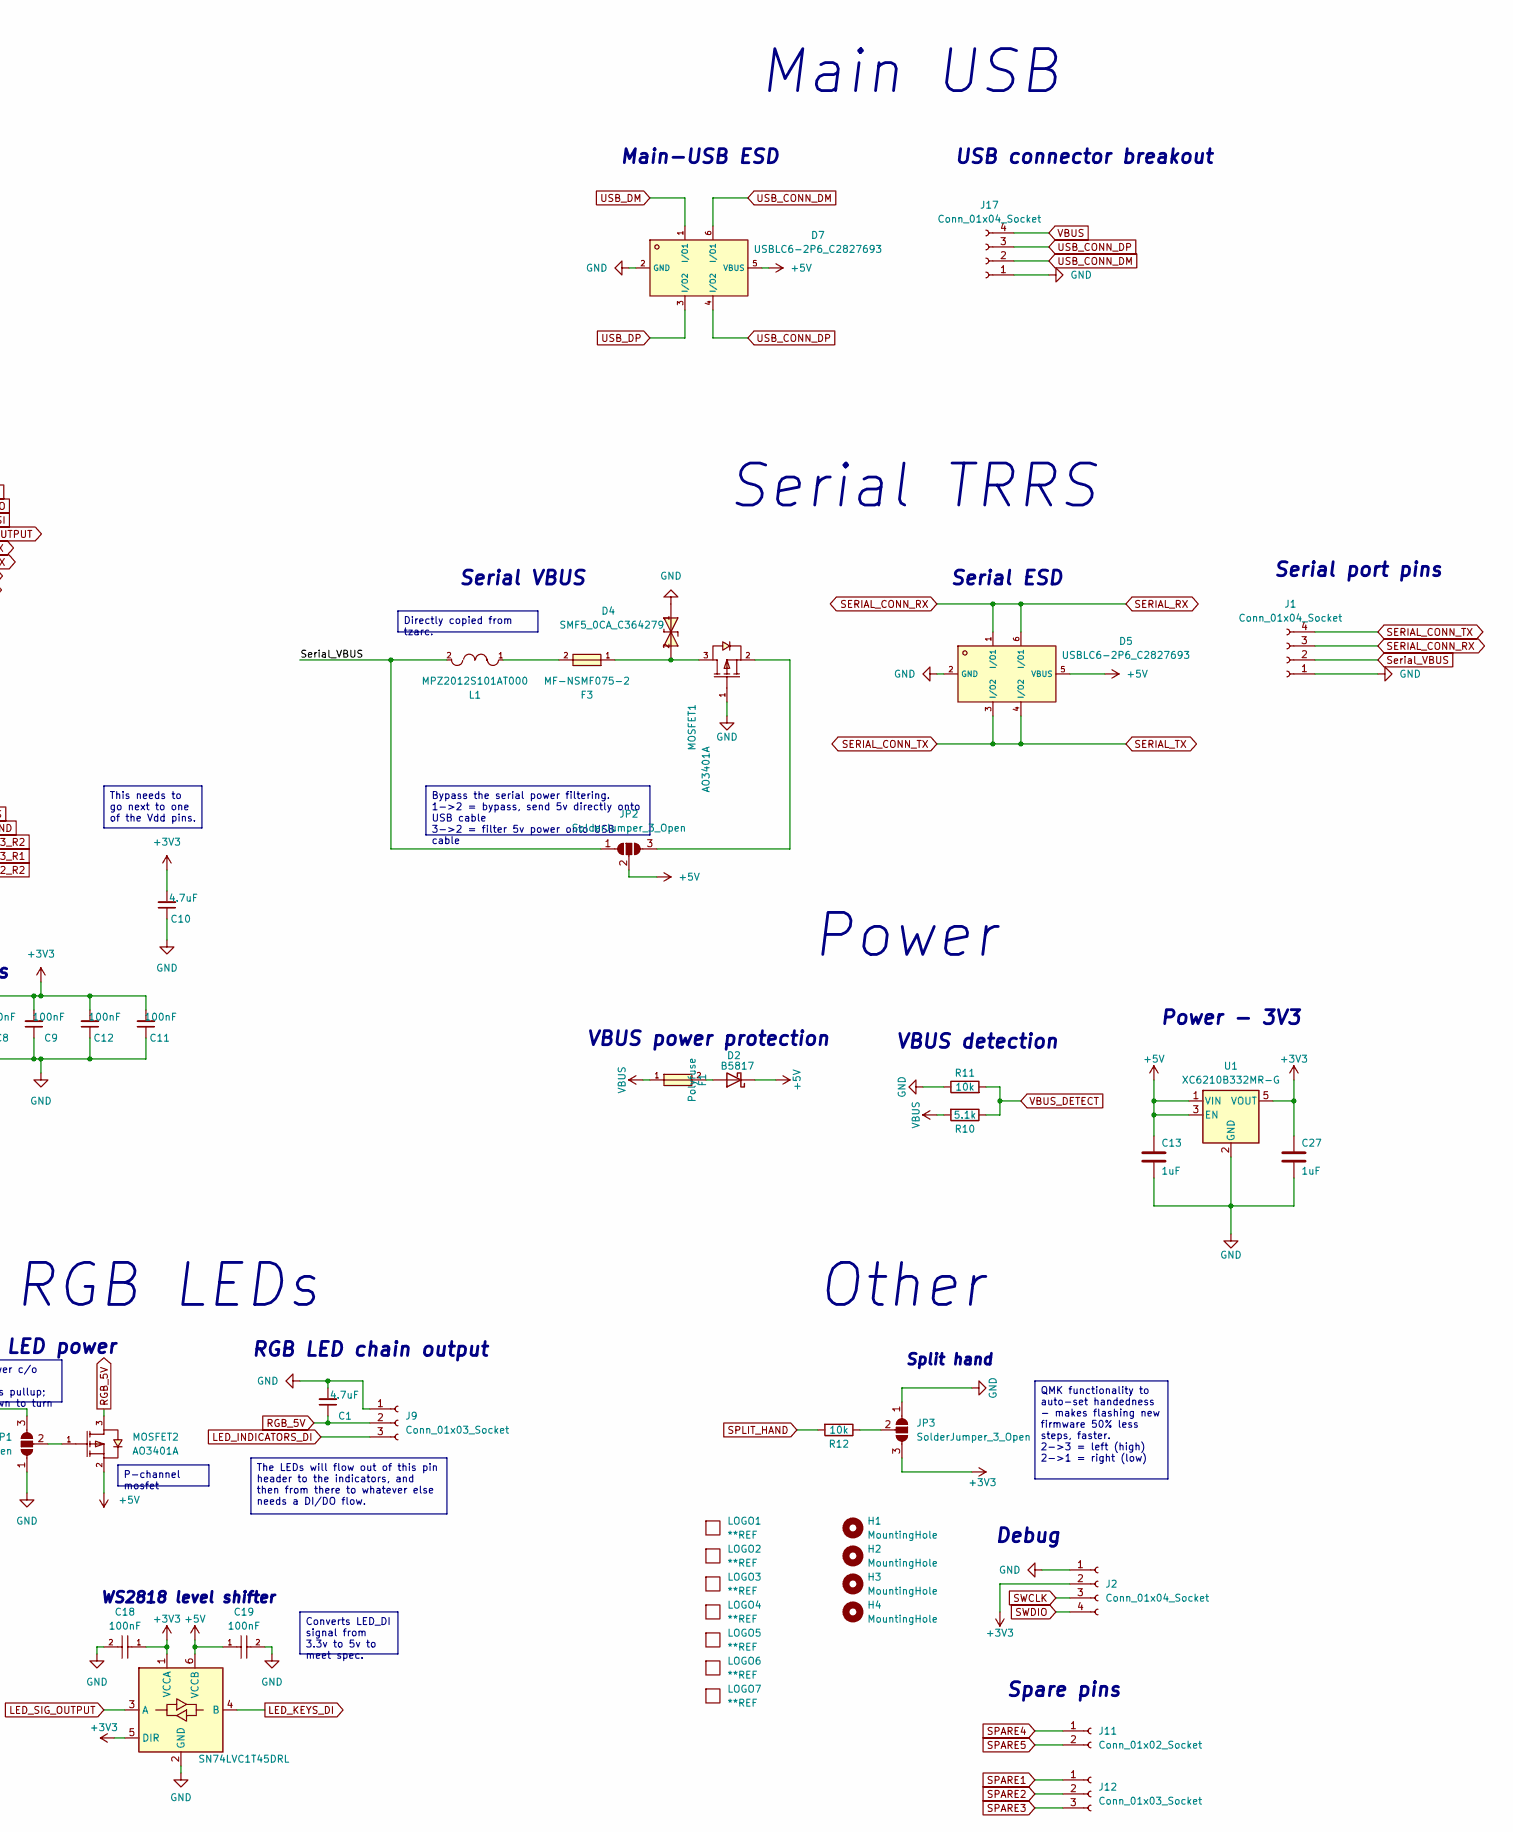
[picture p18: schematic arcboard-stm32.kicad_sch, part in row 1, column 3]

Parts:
C1, C10, C20: 4.7uF; C_0805_2012Metric; LCSC C1779
C2, C4: 2.2uF; C_0402_1005Metric; LCSC C12530
C3, C6: 12p; C_0402_1005Metric; LCSC C1547
C5, C7, C8, C9, C11, C12, C14, C17, C18, C19: 100nF; C_0402_1005Metric; LCSC C1525
C13, C15, C27: 1uF; C_0402_1005Metric; LCSC C52923
C22: CL10A106MA8NRNC; C0603; LCSC C96446
CYBOARD-MAIN1: ECT818001569; FPC-SMD_ECT818001569; LCSC C711420
D2: B5817; D_SOD-323; LCSC C123899
D4: SMF5_0CA_C364279; SOD-123FL_L2.8-W1.8-LS3.7-BI; LCSC C364279
D5, D7: USBLC6-2P6_C2827693; SOT-666-6_L1.6-W1.2-P0.50-LS1.6-BL; LCSC C2827693
F1: Polyfuse; F1206; LCSC C2892424
F3: MF-NSMF075-2; F1206; LCSC C89653
H1, H2, H3, H4: MountingHole; MountingHole_3.2mm_M3_Pad_Via
J1: Conn_01x04_Socket; PinHeader_1x04_P2.54mm_Vertical
J2: Conn_01x04_Socket; PinSocket_1x04_P1.00mm_Vertical
J3, J4, J6, J7, J8, J13, J14, J15, J16: FFC05001-12SBA124W5M; FFC-SMD_FFC05001-12SBA124W5M; LCSC C2833760
J5: Conn_01x02_Socket; PinSocket_1x02_P2.54mm_Vertical
J9: Conn_01x03_Socket; PinHeader_1x03_P2.54mm_Vertical
J10: Conn_01x04_Socket; PinHeader_1x04_P1.00mm_Vertical
J11: Conn_01x02_Socket; PinHeader_1x02_P1.00mm_Vertical
J12: Conn_01x03_Socket; PinHeader_1x03_P1.00mm_Vertical
J17: Conn_01x04_Socket; JST_XH_S4B-XH-A_1x04_P2.50mm_Horizontal
JP1, JP4: SolderJumper_3_Open; SolderJumper-3_P1.3mm_Open_RoundedPad1.0x1.5mm
JP2, JP3: SolderJumper_3_Open; SolderJumper-3_P1.3mm_Open_Pad1.0x1.5mm
L1: MPZ2012S101AT000; L0805; LCSC C15957
LED-LVL1: SN74LVC1T45DRL; SOT-563_L1.6-W1.2-P0.50-LS1.6-BR; MPN SN74LVC1T45DRLR; JLC Basic N
LOGO1, LOGO2: **REF; awesome-logo
LOGO3: **REF; cyboard-logo-10mm
LOGO4: **REF; qmk-lite
LOGO5: **REF; arcboard-stm32-qr-code-10x10
LOGO6: **REF; cyboard-logo-5mm
LOGO7: **REF; awesome-logo-25mm
MOSFET1, MOSFET2, MOSFET3: AO3401A; SOT-23_L2.9-W1.3-P1.90-LS2.4-BR; LCSC C15127
R1: 0402WGF1004TCE; R_0402_1005Metric; LCSC C26083
R2, R3, R7, R8, R11, R12, R16: 10k; R_0402_1005Metric; LCSC C25744
R6: 0603WAF3303T5E; R0603; LCSC C23137
R9: 0402WGF1003TCE; R_0402_1005Metric; LCSC C25741
R10: 5.1k; R_0402_1005Metric; LCSC C25905
R14: 0402WGF1000TCE; R_0402_1005Metric; LCSC C25076
R15: 0402WGF1001TCE; R_0402_1005Metric; LCSC C11702
U1: XC6210B332MR-G; SOT-23-5; LCSC C82942
U3: STM32F405RGTx; LQFP-64_10x10mm_P0.5mm; LCSC C15742
U4, U13: 2N7002; SOT-23-3_L2.9-W1.3-P1.90-LS2.4-BR; LCSC C8545
U5, U6, U7, U8, U9: BAV70S,115; SOT-363-6_L2.0-W1.3-P0.65-LS2.1-BL; LCSC C455031
U10: 1N4148W_C81598; SOD-123F_L2.7-W1.6-LS3.8-RD; LCSC C81598
U14: W25Q128JVSIQTR; SOIC-8_L5.3-W5.3-P1.27-LS8.0-BL; LCSC C97521
U15: TS-1187A-B-A-B; SW-SMD_4P-L5.1-W5.1-P3.70-LS6.5-TL_H1.5; LCSC C318884
Y1: Crystal_GND24; CRYSTAL-SMD_4P-L3.2-W2.5-BL-1; LCSC C9002

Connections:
+3V3: C5.2, C7.2, C8.2, C9.2, C10.2, C11.2, C12.2, C14.2, C18.1, C27.1, J2.2, J3.1 (3V3), J5.1, J10.3, J13.1 (3V3), J14.1 (3V3), J15.1 (3V3), JP3.3 (B), LED-LVL1.1 (VCCA), LED-LVL1.5 (DIR), MOSFET3.2 (S), R7.1, R8.1, U1.5 (VOUT), U3.1 (VBAT), U3.13 (VDDA), U3.19 (VDD), U3.32 (VDD), U3.48 (VDD), U3.64 (VDD), U14.3 (IO2), U14.7 (IO3), U14.8 (VCC), U15.1 (A), U15.2 (B)
+5V: C13.1, C19.1, D2.1 (K), D5.5 (VBUS), D7.5 (VBUS), JP2.2 (C), LED-LVL1.6 (VCCB), MOSFET2.2 (S), U1.1 (VIN), U1.3 (EN)
BOOT0: C22.1, J10.4, R1.1, R2.2, R6.2, U3.60 (BOOT0)
COL0: CYBOARD-MAIN1.2, U3.58 (PB6)
COL1: CYBOARD-MAIN1.20, U3.4 (PC15)
COL2: CYBOARD-MAIN1.21, U3.3 (PC14)
COL3: CYBOARD-MAIN1.22, U3.2 (PC13)
COL4: CYBOARD-MAIN1.17, U3.56 (PB4)
COL5: CYBOARD-MAIN1.7, U3.57 (PB5)
COL6: CYBOARD-MAIN1.6, J6.7 (GP_AD1), U3.55 (PB3), U5.1, U5.3, U5.6
COL7: CYBOARD-MAIN1.25, J6.8 (MOSI), U3.53 (PC12), U6.1, U6.6, U8.6
COL8: J6.9 (GP_AD2), U3.52 (PC11), U6.3, U6.4, U8.3
COL9: J6.10 (SPI_CS), U3.51 (PC10), U7.1, U7.6, U9.6
COL10: J6.11 (MISO), U3.50 (PA15), U7.3, U7.4, U9.3
ENCODER1_R1: J14.7 (GP_AD1), U3.39 (PC8)
ENCODER1_R2: J14.9 (GP_AD2), U3.38 (PC7)
ENCODER2_R1: J15.7 (GP_AD1), U3.37 (PC6)
ENCODER2_R2: J15.9 (GP_AD2), U3.36 (PB15)
ENCODER3_R1: J3.7 (GP_AD1), U3.35 (PB14)
ENCODER3_R2: J3.9 (GP_AD2), U3.34 (PB13)
FLASH_CS: U3.30 (PB11), U14.1 (CS#)
GND: C1.2, C2.1, C3.2, C4.1, C5.1, C6.2, C7.1, C8.1, C9.1, C10.1, C11.1, C12.1, C13.2, C14.1, C15.2, C17.1, C18.2, C19.2, C20.1, C22.2, C27.2, CYBOARD-MAIN1.8, CYBOARD-MAIN1.9, CYBOARD-MAIN1.10, CYBOARD-MAIN1.11, CYBOARD-MAIN1.26, CYBOARD-MAIN1.27, D4.1 (K), D5.2 (GND), D7.2 (GND), J1.1, J2.1, J3.2 (GND), J3.13 (PAD), J3.14 (PAD), J4.1 (3V3), J4.2 (GND), J4.12 (SCLK), J4.13 (PAD), J4.14 (PAD), J6.1 (3V3), J6.2 (GND), J6.12 (SCLK), J6.13 (PAD), J6.14 (PAD), J7.1 (3V3), J7.2 (GND), J7.12 (SCLK), J7.13 (PAD), J7.14 (PAD), J8.1 (3V3), J8.2 (GND), J8.12 (SCLK), J8.13 (PAD), J8.14 (PAD), J9.1, J10.1, J13.2 (GND), J13.13 (PAD), J13.14 (PAD), J14.2 (GND), J14.13 (PAD), J14.14 (PAD), J15.2 (GND), J15.13 (PAD), J15.14 (PAD), J16.2 (GND), J16.13 (PAD), J16.14 (PAD), J17.1, JP1.1 (A), JP3.1 (A), JP4.1 (A), LED-LVL1.2 (GND), MOSFET1.1 (G), R1.2, R9.2, R11.1, R16.1, U1.2 (GND), U3.12 (VSSA), U3.18 (VSS), U3.63 (VSS), U4.2 (S), U13.2 (S), U14.4 (GND), Y1.2, Y1.4
LCD_3V3: C15.1, J16.1 (3V3), MOSFET3.3 (D)
LCD_BL: J16.11 (MISO), U3.28 (PB2)
LCD_CS: J16.10 (SPI_CS), U3.25 (PC5)
LCD_DC: J16.7 (GP_AD1), U3.26 (PB0)
LCD_ON: JP4.3 (B), R8.2, U3.29 (PB10)
LCD_RST: J16.9 (GP_AD2), U3.27 (PB1)
LED_DPAD_DI: CYBOARD-MAIN1.1, J6.4 (SCL)
LED_INDICATORS_DI: J8.4 (SCL), J9.3
LED_KEYS_DI: CYBOARD-MAIN1.12, LED-LVL1.4 (B)
LED_PADDLE1_DI: J4.5 (RGB_DO), J6.5 (RGB_DO)
LED_PADDLE2_DI: J4.4 (SCL), J7.5 (RGB_DO)
LED_PADDLE3_DI: J7.4 (SCL), J8.5 (RGB_DO)
LED_SIG_OUTPUT: LED-LVL1.3 (A), U3.41 (PA8)
NRST: C17.2, J10.2, R14.2, U3.7 (NRST)
unnamed: D2.2 (A), F1.2
unnamed: D4.2 (A), F3.1, MOSFET1.3 (D)
unnamed: F3.2, L1.1
unnamed: J4.7 (GP_AD1), U5.2
unnamed: J4.9 (GP_AD2), U6.5
unnamed: J4.11 (MISO), U7.5
unnamed: J4.8 (MOSI), U6.2
unnamed: J4.10 (SPI_CS), U7.2
unnamed: J5.2, R15.1, U10.2 (A), U15.3 (C), U15.4 (D)
unnamed: J7.7 (GP_AD1), U5.4
unnamed: J7.9 (GP_AD2), U8.4
unnamed: J7.11 (MISO), U9.4
unnamed: J7.8 (MOSI), U8.1
unnamed: J7.10 (SPI_CS), U9.1
unnamed: J8.7 (GP_AD1), U5.5
unnamed: J8.9 (GP_AD2), U8.5
unnamed: J8.11 (MISO), U9.5
unnamed: J8.8 (MOSI), U8.2
unnamed: J8.10 (SPI_CS), U9.2
unnamed: JP1.2 (C), MOSFET2.1 (G)
unnamed: JP2.3 (B), MOSFET1.2 (S)
unnamed: JP3.2 (C), R12.1
unnamed: JP4.2 (C), MOSFET3.1 (G)
unnamed: C2.2, U3.31 (VCAP_1)
unnamed: C4.2, U3.47 (VCAP_2)
unnamed: R2.1, U4.3 (D)
unnamed: R3.2, R9.1, U4.1 (G)
unnamed: R6.1, U10.1 (K)
unnamed: R3.1, R14.1, U13.3 (D)
unnamed: R15.2, R16.2, U13.1 (G)
PH0: C3.1, U3.5 (PH0), Y1.1
PH1: C6.1, U3.6 (PH1), Y1.3
PMW_CS: J13.10 (SPI_CS), U3.24 (PC4)
RGB_5V: C1.1, C20.2, CYBOARD-MAIN1.13, CYBOARD-MAIN1.14, CYBOARD-MAIN1.15, CYBOARD-MAIN1.16, J4.3 (SDA), J6.3 (SDA), J7.3 (SDA), J8.3 (SDA), J9.2, MOSFET2.3 (D)
RGB_ON: JP1.3 (B), R7.2, U3.40 (PC9)
ROW0: CYBOARD-MAIN1.3, U3.8 (PC0)
ROW1: CYBOARD-MAIN1.4, U3.9 (PC1)
ROW2: CYBOARD-MAIN1.18, U3.10 (PC2)
ROW3: CYBOARD-MAIN1.5, U3.11 (PC3)
ROW4: CYBOARD-MAIN1.23, J4.6 (5V), U3.14 (PA0)
ROW5: CYBOARD-MAIN1.19, J6.6 (5V), J7.6 (5V), U3.15 (PA1)
ROW6: CYBOARD-MAIN1.24, J8.6 (5V), U3.16 (PA2)
SERIAL_CONN_RX: D5.1 (I/O1), D5.6 (I/O1), J1.3, U3.43 (PA10)
SERIAL_CONN_TX: D5.3 (I/O2), D5.4 (I/O2), J1.4, U3.42 (PA9)
SPARE1: J12.1, U3.59 (PB7)
SPARE2: J12.2, U3.61 (PB8)
SPARE3: J12.3, U3.62 (PB9)
SPARE4: J11.1, U3.17 (PA3)
SPARE5: J11.2, U3.20 (PA4)
SPI1_CLK: J13.12 (SCLK), J16.12 (SCLK), U3.21 (PA5), U14.6 (CLK)
SPI1_MISO: J13.11 (MISO), U3.22 (PA6), U14.2 (DO)
SPI1_MOSI: J13.8 (MOSI), J16.8 (MOSI), U3.23 (PA7), U14.5 (DI)
SPLIT_HAND: R12.2, U3.33 (PB12)
SWCLK: J2.3, U3.49 (PA14)
SWDIO: J2.4, U3.46 (PA13)
Serial_VBUS: J1.2, JP2.1 (A), L1.2
USB_CONN_DM: D7.6 (I/O1), J17.2
USB_CONN_DP: D7.4 (I/O2), J17.3
USB_DM: D7.1 (I/O1), U3.44 (PA11)
USB_DP: D7.3 (I/O2), U3.45 (PA12)
VBUS: F1.1, J17.4, R10.2
VBUS_DETECT: R10.1, R11.2, U3.54 (PD2)

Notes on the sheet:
Spare pins
Serial port pins
PMW connector
Power
DFU, RESET, BOOT Buttons
Serial ESD
USB connector breakout
VBUS detection
VBUS power protection
DPAD1/PAD1 COL9/10
Main-USB ESD
RGB LEDs
Split hand
Cyboard flex-pcb main 25-pin connector
Dpad & paddle-dpads
ROW2COL - Keys, dpads
Power - 3V3
Other
DPAD1/PAD1 COL7/8
Debug
v1.1: Moved from 8mhz to 12mhz crystal, to satisfy QMK defaults.
PAD2/3 COL9/10
Encoders
WS2818 level shifter
The boot loader is located in system memory. It is used to reprogram the flash memory by using USART1 (PA9/PA10), USART3 (PC10/PC11 or PB10/PB11), CAN2 (PB5/PB13), USB OTG FS in Device mode (PA11/PA12) through DFU (device firmware upgrade).
Encoder1 (top, back)
CPU caps
MCU; power, timing, & boot
Crystal
PAD2/PAD3 COL7/8
SPI External flash
Serial TRRS
Main USB
SPI devices
Encoder3 (ring)
RGB LED chain output
RGB LED power
Serial VBUS
LCD power
Encoder2 (top, front)

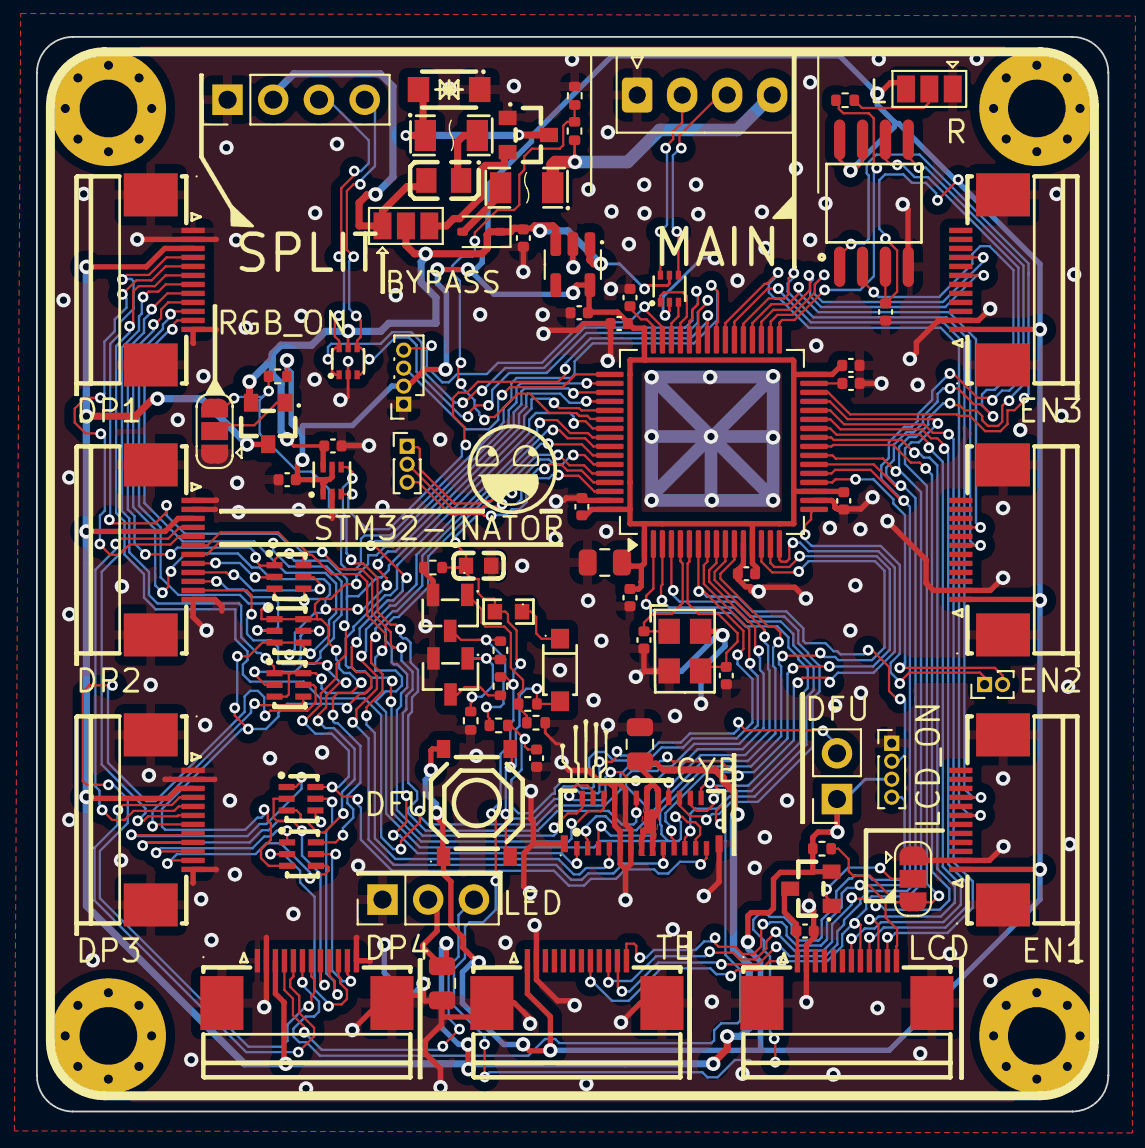
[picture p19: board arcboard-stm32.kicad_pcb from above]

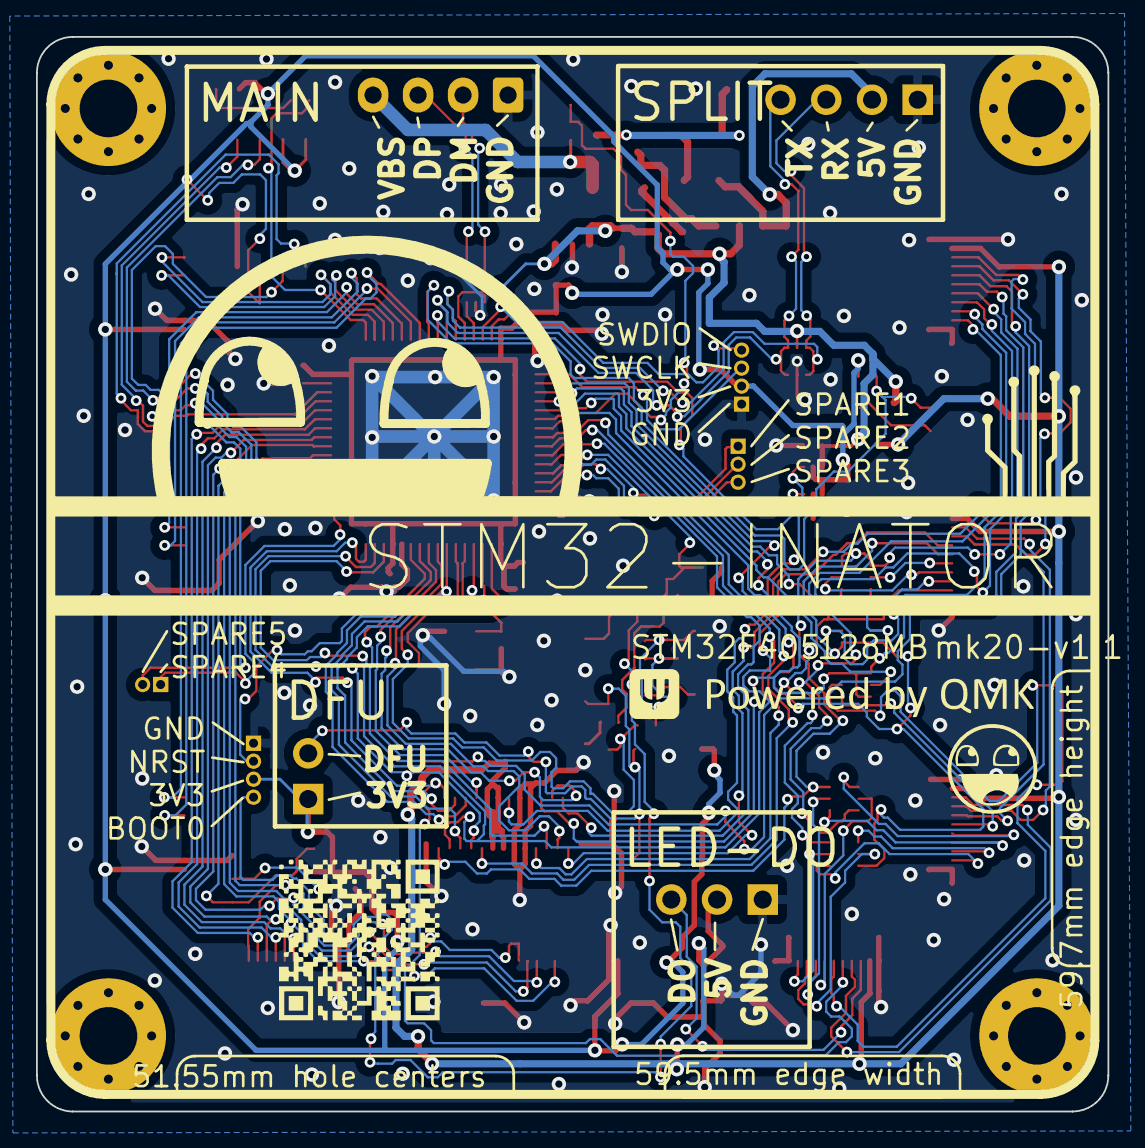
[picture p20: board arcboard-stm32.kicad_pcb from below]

Board: 2 copper layers, 59.5 x 59.7 mm, 91 parts (5 on the bottom side), 98 nets.

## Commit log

2025-07-21 initial commit, bare project
    [arcboard-stm32.kicad_pcb, arcboard-stm32.kicad_sch]
2025-07-24 savegame jul23
    [arcboard-stm32.kicad_pcb, arcboard-stm32.kicad_sch]
2025-07-26 mostly there
    [arcboard-stm32.kicad_pcb, arcboard-stm32.kicad_sch]
2025-07-27 cleaned up routing quite a bit
    [arcboard-stm32.kicad_pcb, arcboard-stm32.kicad_sch]
2025-07-28 more trace pruning
    [arcboard-stm32.kicad_pcb]
2025-07-28 prepping for review
    [arcboard-stm32.kicad_pcb, arcboard-stm32.kicad_sch]
2025-08-15 before removal of usb port
    [arcboard-stm32.kicad_pcb, arcboard-stm32.kicad_sch]
2025-08-15 moving to separate split connector, adding flash
    [arcboard-stm32.kicad_pcb, arcboard-stm32.kicad_sch]
2025-08-15 adding spare pins, more routing
    [arcboard-stm32.kicad_pcb, arcboard-stm32.kicad_sch]
2025-08-24 silkscreen updates
    [arcboard-stm32.kicad_pcb, arcboard-stm32.kicad_sch]
2025-08-24 silkscreen improvements
    [arcboard-stm32.kicad_pcb, arcboard-stm32.kicad_sch]
2025-08-24 moved a few items, silkscreen improvements
    [arcboard-stm32.kicad_pcb, arcboard-stm32.kicad_sch]
2025-08-26 production version
    [arcboard-stm32.kicad_pcb, arcboard-stm32.kicad_sch]
2025-08-26 3d model weirdness
    [arcboard-stm32.kicad_pcb]
2025-09-07 fixing bad mosfet configuration, changing crystal to 12mhz
    [arcboard-stm32.kicad_pcb, arcboard-stm32.kicad_sch]
